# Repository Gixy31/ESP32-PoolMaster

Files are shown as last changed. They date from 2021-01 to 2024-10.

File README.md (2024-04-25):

<h2>ESP32 PoolMaster</h2>
<h4>Brief description</h4>
<p> This project is a software port to an ESP32 platform of the PoolMaster project from Loic74650 (https://github.com/Loic74650/PoolMaster)<br />
Compared to the initial project, the main differences are:
<ul>
  <li> ESP32 MCU with WiFi (multiple access points)</li>
  <li> ESP32-Arduino framework, PlatformIO IDE </li>
  <li> async MQTT client</li>
  <li> JSON upgrade to version 6</li>
  <li> lots of code modifications, keeping the general behaviour</li>
  <li> add a fourth pump (cleaning robot)</li>
  <li> manage only 2 relays (+ the four pumps)</li>
  <li> analog measurements done by external ADC I2C module (ADS1115), in async mode</li>
  <li> and more...
</ul>  <br />
  The project isn't a fork of the original one due to the different structure of source files with PlatformIO ((.cpp, .h).
  A dedicated board has been designed to host all components. There are 8 LEDs at the bottom to display status, warnings and alarms.
  <br /><br />
  In version ESP-3.0, the display function has been very simplified (twice less code), using Nextion variables only to deport the logic 
  into the Nextion and updating the display only when it is ON. 
  <br /><br />
  A new version of the board allows the connection of the pH_Orp board from Loïc (https://github.com/Loic74650/pH_Orp_Board/tree/main)  on an additional I2C connector. The sofware is modified accordingly. The configuration is defined in the config.h file. CAD_files 2 Gerber 3 files are provided.
  <br /><br />
  The version V6, (aka ESP-2.0) implement direct usage of FreeRTOS functions for managing tasks and queues. There are 10 tasks sharing the
  app_CPU :
  - The Arduino loopTask, with only the setup() function. When the setup is finished, the task deletes itself to recover memory;
  - PoolMaster, running every 500ms, which mainly supervises the overall timing of the system;
  - AnalogPoll, running every 125ms, to acquire analog measurements of pH, ORP and Pressure with an ADS115 sensor on an I2C bus;
  - GetTemp, running every 1000ms, to acquire water and air temperatures with DS18B20 sensors on two 1Wire busses;
  - ORPRegulation, running every 1000ms, to manage Chlorine pump;
  - pHRegulation, running every 1000ms, to manage Acid/Soda pump;
  - ProcessCommand, running every 500ms, to process commands received on /Home/Pool6/API MQTT Topic;
  - SettingsPublish, running when notified only (e.g with external command), to publish settings on the MQTT topic;
  - MeasuresPublish, running every 30s and when notified, to publish actual measures and status;
  - StatusLights, running every 3000ms, to display a row of 8 status LEDs on the mother board, through a PCF8574A on the I2C bus.

  </p><br /><br />

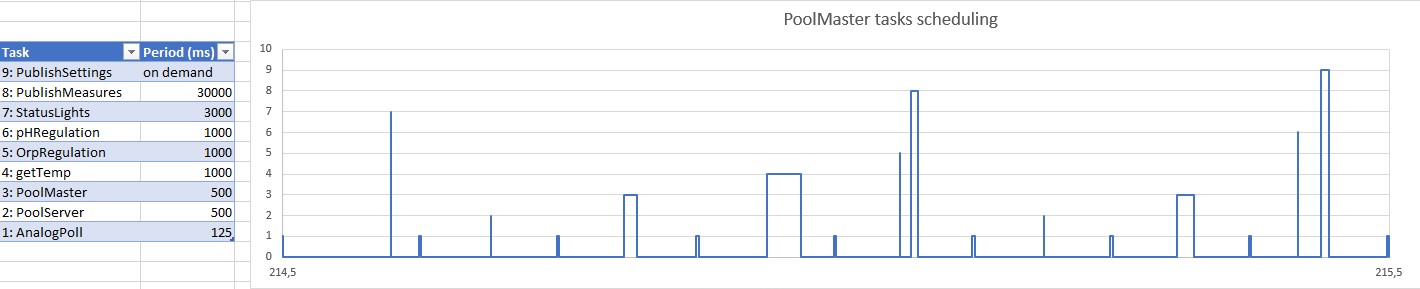
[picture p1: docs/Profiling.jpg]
  <br /><br />
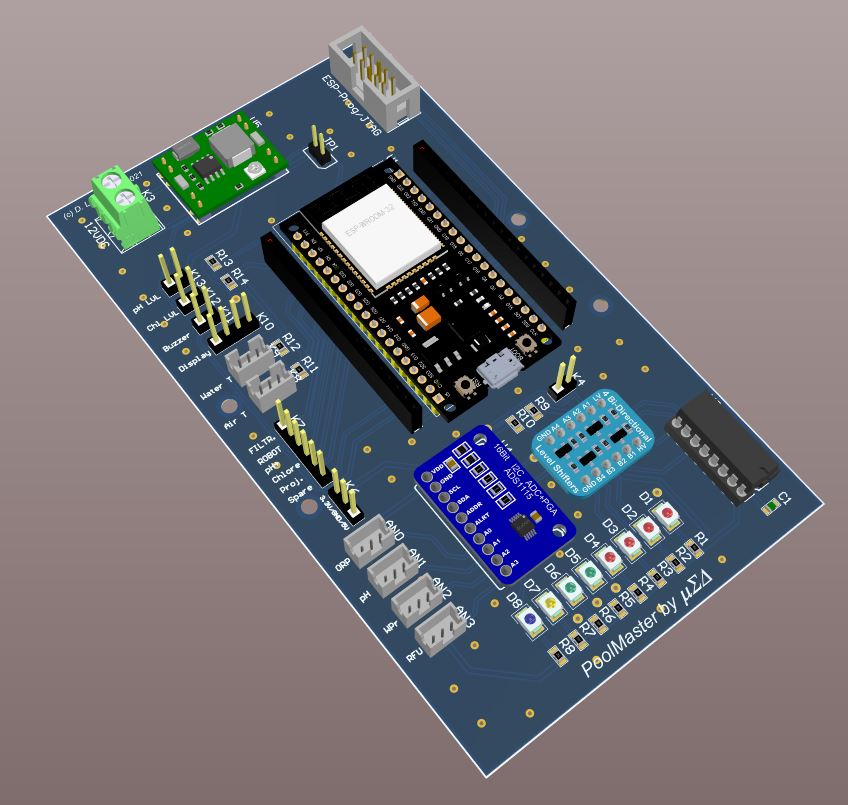
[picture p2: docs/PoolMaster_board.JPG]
Board
 <br /><br />  
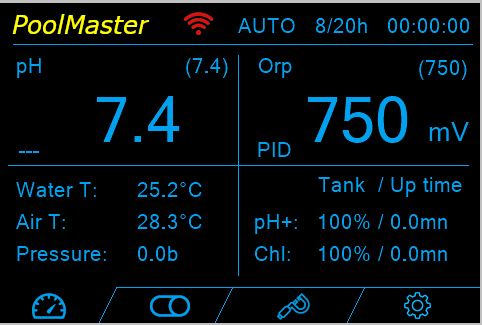
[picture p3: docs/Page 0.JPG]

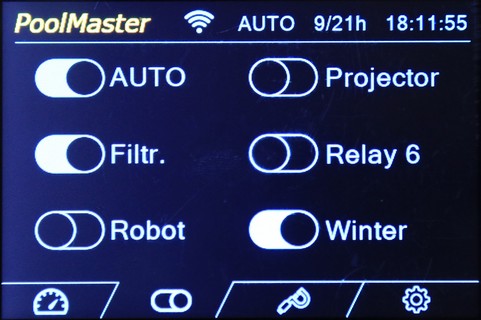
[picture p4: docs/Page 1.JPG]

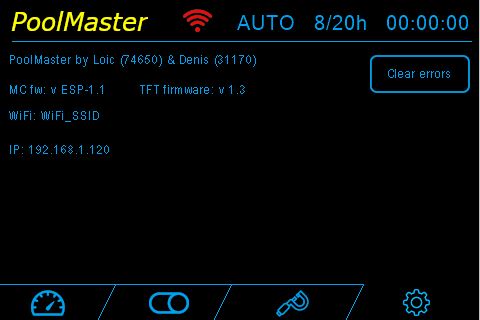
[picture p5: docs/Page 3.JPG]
<br /><br />  

<h2>PoolMaster 5.0.0</h2>
<h2>Arduino Mega2560 (or Controllino-Maxi) Ph/Orp (Chlorine) regulation system for home pools</h2>

<br />
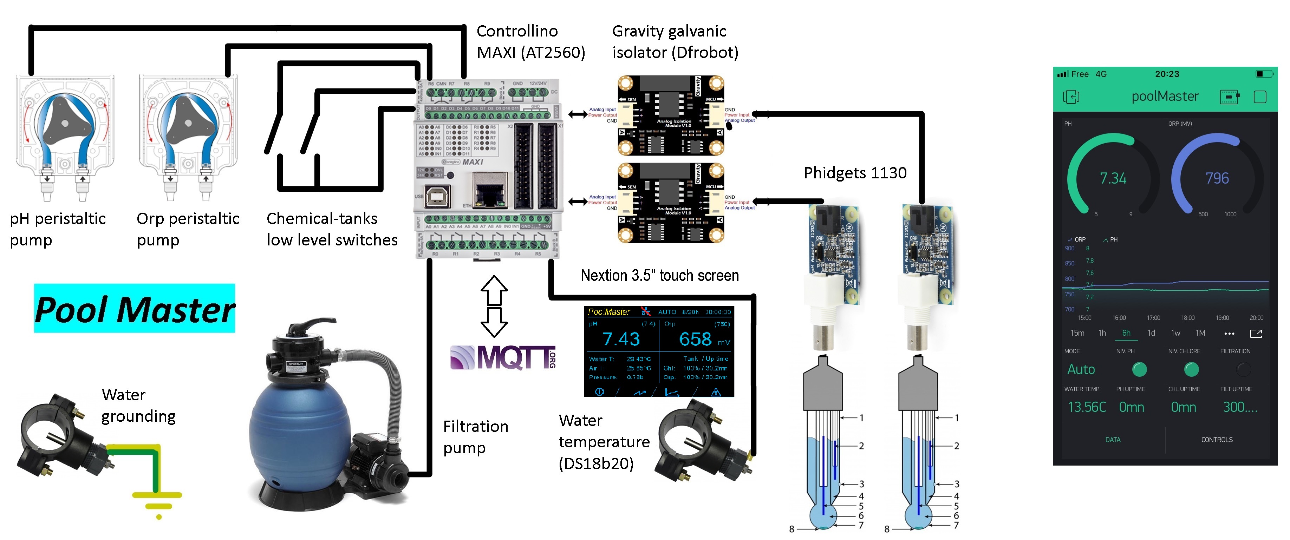
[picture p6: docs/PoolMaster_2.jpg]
 <br /><br />

<br />
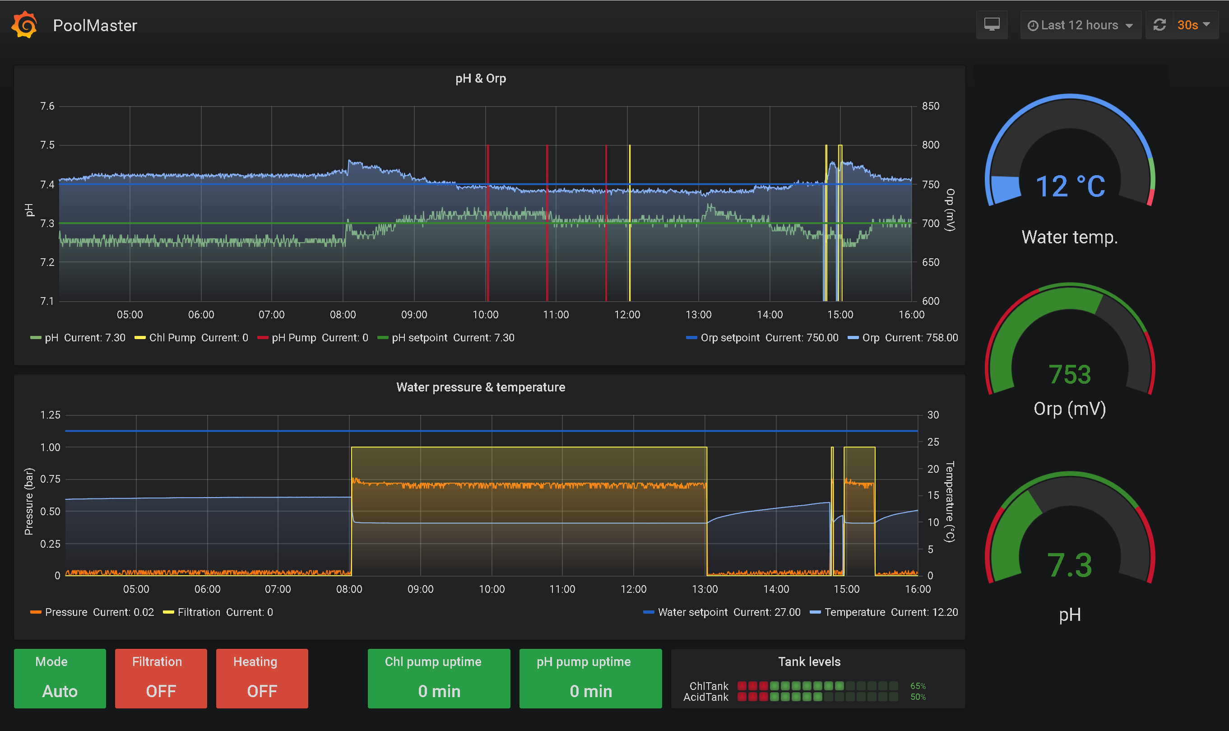
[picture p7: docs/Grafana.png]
Dashboard
 <br /><br />

<br />
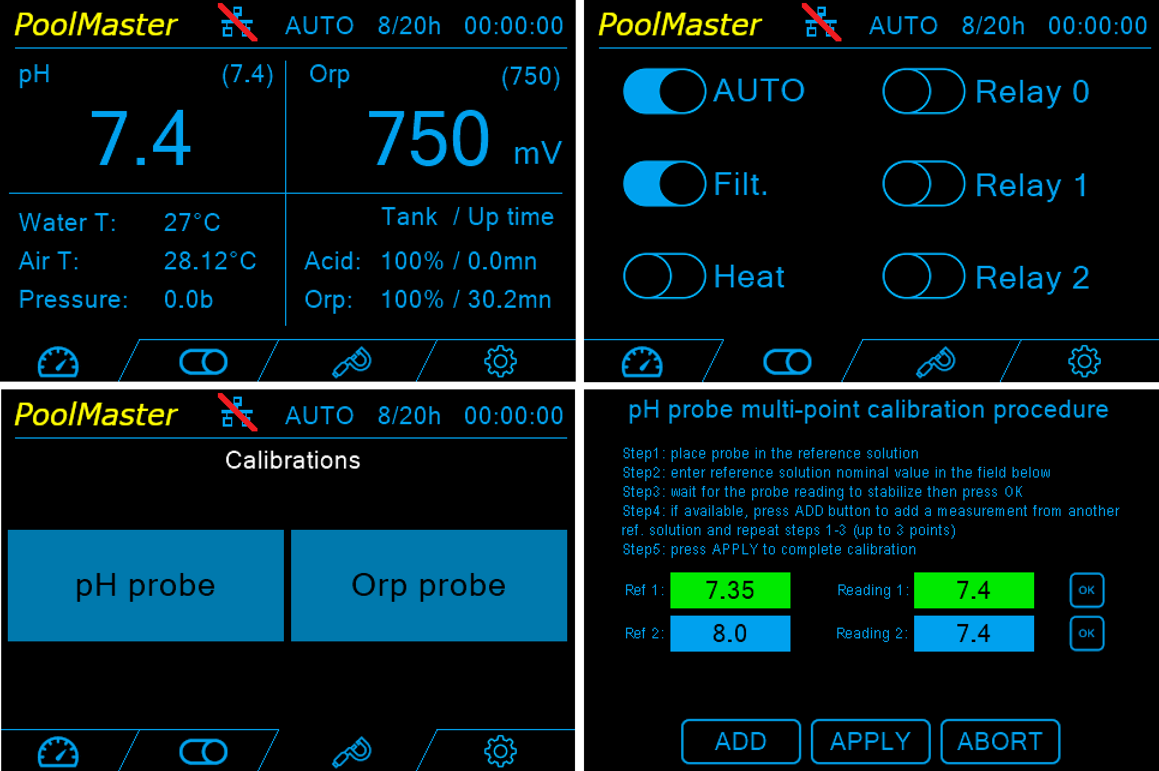
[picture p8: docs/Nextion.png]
Nextion 3.5
<p align="center"> 
Pumps states, tank-levels estimates and other parameters are also periodically reported<br />
Two PID regulation loops are running in parallel: one for PH, one for ORP<br />
An additional simple (on/off) regulation loop is handling the water temperature (it starts/stops the house-heating system circulator which brings heat to a heat exchanger mounted on the pool water pipes)<br />
pH is regulated by injecting Acid from a tank into the pool water (a relay starts/stops the Acid peristaltic pump)<br />
ORP is regulated by injecting Chlorine from a tank into the pool water (a relay starts/stops the Chlorine peristaltic pump)<br />
Defined time-slots and water temperature are used to start/stop the filtration pump for a daily given amount of time (a relay starts/stops the filtration pump)<br />
Tank-levels are estimated based on the running-time and flow-rate of each pump.<br />
Ethernet connectivity parameters can be set through a webpage accessible from the LAN at http://PoolMaster.local.<br />
If an ethernet connection is available, the internal clock (RTC) is synchronized with a time-server every day at midnight.<br />

An API function enables telling the system what the outside air temperature is. In case it is below -2.0°C, filtration is started until it rises back above +2.0°C<br />
Communication with the system is performed using the MQTT protocol over an Ethernet connection to the local network/MQTT broker.<br /><br />

Every 30 seconds (by default), the system will publish on the "PoolTopicMeas1" and "PoolTopicMeas2"(see in code below) the following payloads in Json format:<br />
  {"Tmp":818,"pH":321,"PSI":56,"Orp":583,"FilUpT":8995,"PhUpT":0,"ChlUpT":0}<br />
  {"AcidF":100,"ChlF":100,"IO":11,"IO2":0}<br />
  Tmp: measured Water temperature value in °C x100 (8.18°C in the above example payload)<br />
  pH: measured pH value x100 (3.21 in the above example payload)<br />
  Orp: measured Orp (aka Redox) value in mV (583mV in the above example payload)<br />
  PSI: measured Water pressure value in bar x100 (0.56bar in the above example payload)<br />
  FiltUpT: current running time of Filtration pump in seconds (reset every 24h. 8995secs in the above example payload)<br />
  PhUpT: current running time of Ph pump in seconds (reset every 24h. 0secs in the above example payload)<br />
  ChlUpT: current running time of Chl pump in seconds (reset every 24h. 0secs in the above example payload)<br />
  AcidF: percentage fill estimate of acid tank ("pHTank" command must have been called when a new acid tank was set in place in order to have accurate value)<br />
  ChlF: percentage fill estimate of Chlorine tank ("ChlTank" command must have been called when a new Chlorine tank was set in place in order to have accurate value)<br />
IO: a variable of type BYTE where each individual bit is the state of a digital input on the Arduino. These are :<br />	
<ul>
<li>FiltPump: current state of Filtration Pump (0=on, 1=off)</li>
<li>PhPump: current state of Ph Pump (0=on, 1=off)</li>
<li>ChlPump: current state of Chl Pump (0=on, 1=off)</li>
<li>PhlLevel: current state of Acid tank level (0=empty, 1=ok)</li>
<li>ChlLevel: current state of Chl tank level (0=empty, 1=ok)</li>
<li>PSIError: over-pressure error</li>
<li>pHErr: pH pump overtime error flag</li>
<li>ChlErr: Chl pump overtime error flag</li>
</ul><br />
IO2: a variable of type BYTE where each individual bit is the state of a digital input on the Arduino. These are :<br /><br />
<ul>
<li>pHPID: current state of pH PID regulation loop (1=on, 0=off)</li>
<li>OrpPID: current state of Orp PID regulation loop (1=on, 0=off)</li>
<li>Mode: state of pH and Orp regulation mode (0=manual, 1=auto)</li>
<li>Heat: state of water heat command (0=off, 1=on)</li>
<li>R1: state of Relay1 (0=off, 1=on)</li>
<li>R2: state of Relay2 (0=off, 1=on)</li>
<li>R6: state of Relay6 (0=off, 1=on)</li>
<li>R7: state of Relay7 (0=off, 1=on)</li>
</ul><br />

<h4>How to compile</h4>
<p>
- this code was developped for two main hardware configurations (see list in the hardware section below):<br /> 
<ul>
<li>Controllino-Maxi or</li> 
<li>Arduino Mega 2560 + Ethernet shield + relay shield + RTC module</li></ul>
- select the target board type in the Arduino IDE (either "Arduino Mega 2560" or "Controllino Maxi") code should compile for both types<br />

<h4>Compatibility</h4>
	
<p>For this sketch to work on your setup you must change the following in the code (in the "Config.h" file):<br />
- possibly the pinout definitions depending on your wiring<br />
- the unique address of the DS18b20 water temperature sensor<br />
- MAC and IP address of the Ethernet shield<br />
- MQTT broker IP address and login credentials<br />
- possibly the topic names on the MQTT broker to subscribe and publish to<br />
- the Kp,Ki,Kd parameters for both PID loops in case your peristaltic pumps have a different throughput than 1.5Liters/hour for the pH pump and 3.0Liters/hour for the Chlorine pump. Also the default Kp values were adjusted for a 50m3 pool volume. You might have to adjust the Kp values in case of a different pool volume and/or peristaltic pumps throughput (start by adjusting it proportionally). In any case these parameters are likely to require adjustments for every pool<br /></p>

<h4>Tips</h4>
Before attempting to regulate your pool water with this automated system, it is essential that you start with:<br />
1- testing your water quality (using liquid kits and/or test strips for instance) and balancing it properly (pH, Chlorine, Alkalinity, Hardness). Proper water balancing will greatly ease the pH stability and regulation<br />
2- calibrating the pH probe using calibrated buffer solutions (pay attention to the water temperature which plays a big role in pH readings)<br />
3- adjusting pH to 7.4 <br />
4- once above steps 1 to 3 are ok, you can start regulating ORP<br /><br />
 
Notes:<br />
a/ the ORP sensor should theoretically not be calibrated nore temperature compensated (by nature its 0mV pivot point cannot shift)<br />
b/ the ORP reading is strongly affected by the pH value and the water temperature. Make sure pH is adjusted at 7.4<br />
c/ prefer platinium ORP probes for setpoints >500mV (ie. Pools and spas)<br />
e/ the response time of ORP sensors can be fast in reference buffer solutions (10 secs) and yet very slow in pool water (minutes or more) as it depends on the water composition <br /><br />

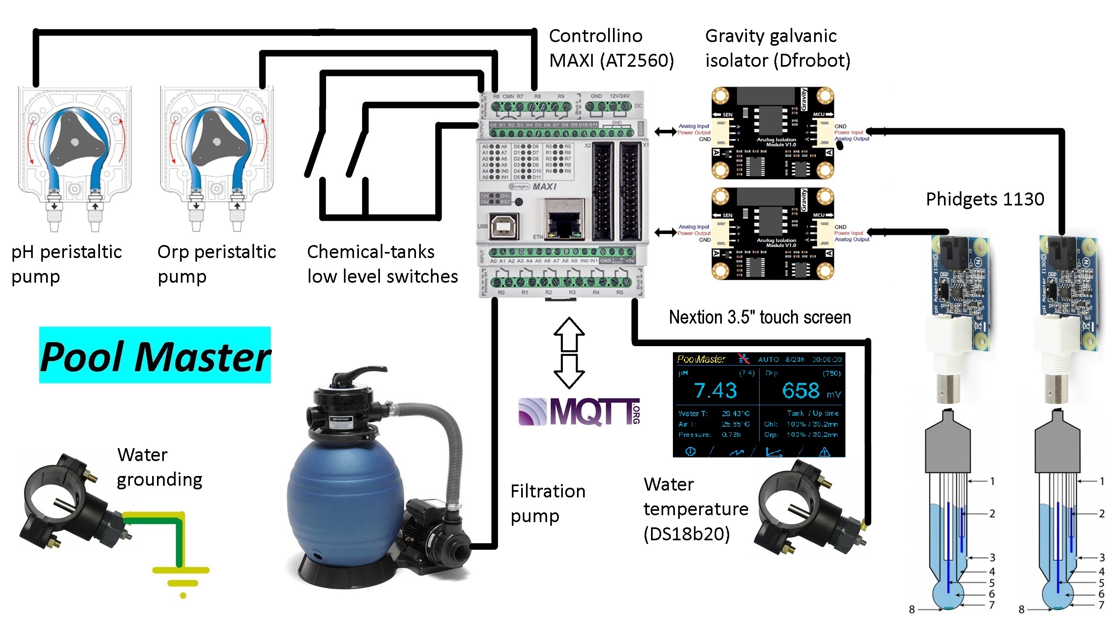
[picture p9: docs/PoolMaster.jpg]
 <br /><br />
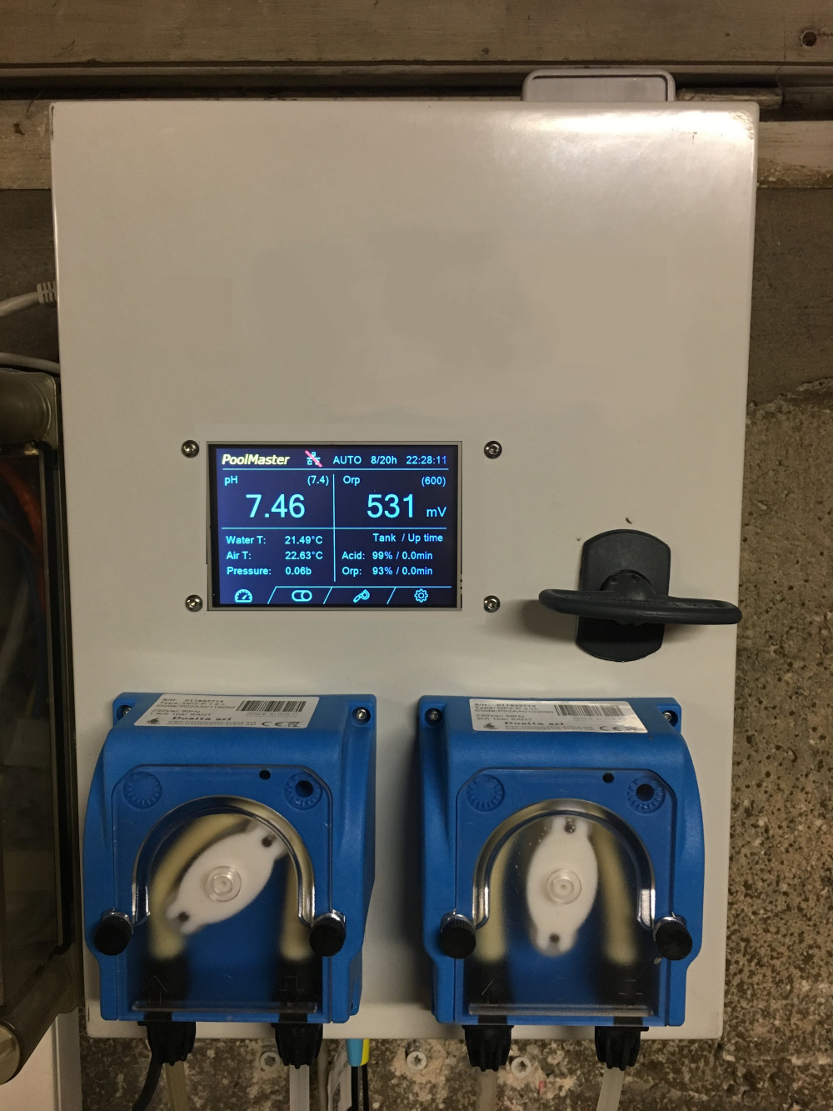
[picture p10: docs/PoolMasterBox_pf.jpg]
 <br /><br />

<h4>MQTT API</h4>
<p>
Below are the Payloads/commands to publish on the "PoolTopicAPI" topic (see hardcoded in code) in Json format in order to launch actions on the Arduino:<br />
<ul>
<li>{"Mode":1} or {"Mode":0}         -> set "Mode" to manual (0) or Auto (1). In Auto, filtration starts/stops at set times of the day and pH and Orp are regulated</li> 
<li>{"Heat":1} or {"Heat":0}         -> start/stop the regulation of the pool water temperature</li>
<li>{"FiltPump":1} or {"FiltPump":0} -> manually start/stop the filtration pump</li>
<li>{"ChlPump":1} or {"ChlPump":0}   -> manually start/stop the Chl pump to add more Chlorine</li>
<li>{"PhPump":1} or {"PhPump":0}     -> manually start/stop the Acid pump to lower the Ph</li>
<li>{"PhPID":1} or {"PhPID":0}       -> start/stop the Ph PID regulation loop</li>
<li>{"OrpPID":1} or {"OrpPID":0}     -> start/stop the Orp PID regulation loop</li>
<li>{"PhCalib":[4.02,3.8,9.0,9.11]}  -> multi-point linear regression calibration (minimum 1 point-couple, 6 max.) in the form [ProbeReading_0, BufferRating_0, xx, xx, ProbeReading_n, BufferRating_n]
<li>{"OrpCalib":[450,465,750,784]}   -> multi-point linear regression calibration (minimum 1 point-couple, 6 max.) in the form [ProbeReading_0, BufferRating_0, xx, xx, ProbeReading_n, BufferRating_n]
<li>{"PhSetPoint":7.4}               -> set the Ph setpoint, 7.4 in this example</li>
<li>{"OrpSetPoint":750.0}            -> set the Orp setpoint, 750mV in this example</li>
<li>{"WSetPoint":27.0}               -> set the water temperature setpoint, 27.0deg in this example</li>
<li>{"WTempLow":10.0}                -> set the water low-temperature threshold below which there is no need to regulate Orp and Ph (ie. in winter)</li>
<li>{"OrpPIDParams":[2857,0,0]}      -> respectively set Kp,Ki,Kd parameters of the Orp PID loop. In this example they are set to 2857, 0 and 0</li>
<li>{"PhPIDParams":[1330000,0,0.0]}  -> respectively set Kp,Ki,Kd parameters of the Ph PID loop. In this example they are set to 1330000, 0 and 0</li>
<li>{"OrpPIDWSize":3600000}           -> set the window size of the Orp PID loop in msec, 60mins in this example</li>
<li>{"PhPIDWSize":1200000}            -> set the window size of the Ph PID loop in msec, 20mins in this example</li>
<li>{"Date":[1,1,1,18,13,32,0]}      -> set date/time of RTC module in the following format: (Day of the month, Day of the week, Month, Year, Hour, Minute, Seconds), in this example: Monday 1st January 2018 - 13h32mn00secs</li>
<li>{"FiltT0":9}                     -> set the earliest hour (9:00 in this example) to run filtration pump. Filtration pump will not run beofre that hour</li>
<li>{"FiltT1":20}                    -> set the latest hour (20:00 in this example) to run filtration pump. Filtration pump will not run after that hour</li>
<li>{"PubPeriod":30}                 -> set the periodicity (in seconds) at which the system info (pumps states, tank levels states, measured values, etc) will be published to the MQTT broker</li>
<li>{"PumpsMaxUp":1800}              -> set the Max Uptime (in secs) for the Ph and Chl pumps over a 24h period. If over, PID regulation is stopped and a warning flag is raised</li>
<li>{"Clear":1}                      -> reset the pH and Orp pumps overtime error flags in order to let the regulation loops continue. "Mode" also needs to be switched back to Auto (1) after an error flag was raised</li>
<li>{"DelayPID":30}                  -> Delay (in mins) after FiltT0 before the PID regulation loops will start. This is to let the Orp and pH readings stabilize first. 30mins in this example. Should not be > 59mins</li>
<li>{"TempExt":4.2}                  -> Provide the system with the external temperature. Should be updated regularly and will be used to start filtration when temperature is less than 2°C. 4.2deg in this example</li>
<li>{"PSIHigh":1.0}                  -> set the water high-pressure threshold (1.0bar in this example). When water pressure is over that threshold, an error flag is set</li>
<li>{"pHTank":[20,100]}              -> call this function when the Acid tank is replaced or refilled. First parameter is the tank volume in Liters, second parameter is its percentage fill (100% when full)</li>
<li>{"ChlTank":[20,100]}             -> call this function when the Chlorine tank is replaced or refilled. First parameter is the tank volume in Liters, second parameter is its percentage fill (100% when full)</li>
<li>{"Relay":[1,1]}                  -> call this generic command to actuate spare relays. Parameter 1 is the relay number (R1 in this example), parameter 2 is the relay state (ON in this example). This command is useful to use spare relays for additional features (lighting, etc). Available relay numbers are 1,2,6,7,8,9</li>
<li>{"Reboot":1}                     -> call this command to reboot the controller (after 8 seconds from calling this command)</li>
<li>{"pHPumpFR":1.5}                 -> call this command to set pH pump flow rate un L/s. In this example 1.5L/s</li>
<li>{"ChlPumpFR":3}                  -> call this command to set Chl pump flow rate un L/s. In this example 3L/s</li>
<li>{"RstpHCal":1}                   -> call this command to reset the calibration coefficients of the pH probe</li>
<li>{"RstOrpCal":1}                  -> call this command to reset the calibration coefficients of the Orp probe</li>
<li>{"RstPSICal":1}                  -> call this command to reset the calibration coefficients of the pressure sensor</li>

</ul>
</p><br />

<h4>Hardware</h4>
<p>
<ul>
<li><a title="https://www.controllino.biz/product/controllino-maxi/" href="https://www.controllino.biz/product/controllino-maxi/">x1 CONTROLLINO MAXI (ATmega2560)</a> or Arduino Mega 2560 + Ethernet shield + relay shield + RTC module</li>
<li><a title="https://www.phidgets.com/?tier=3&catid=11&pcid=9&prodid=103" href="https://www.phidgets.com/?tier=3&catid=11&pcid=9&prodid=103">x2 Phidgets PH/ORB amplifier modules</a></li> 
<li><a title="https://www.dfrobot.com/product-1621.html" href="https://www.dfrobot.com/product-1621.html">x2 Galvanic isolator for the pH and Orp probes</a></li> 
<li><a title="https://www.trattamento-acque.net/dosaggio/pompe-peristaltiche/pompe-a-portata-fissa/pompa-serie-mp2-p-detail.html" href="https://www.trattamento-acque.net/dosaggio/pompe-peristaltiche/pompe-a-portata-fissa/pompa-serie-mp2-p-detail.html">x2 Peristaltic pumps, suction lances for tanks, pH and Orp probes</a></li>
<li><a title="http://electrolyseur.fr/pool-terre.html" href="http://electrolyseur.fr/pool-terre.html">x1 Water grounding</a></li>
<li><a title="http://electrolyseur.fr/kit-sonde-DS18B20-filtration-piscine.html" href="http://electrolyseur.fr/kit-sonde-DS18B20-filtration-piscine.html">x1 Water temperature probe (DS18B20)</a></li>
<li><a title="https://fr.aliexpress.com/item/OOTDTY-G1-4-Pouces-5-v-0-0-5-MPa-Pression-Capteur-Capteur-D-huile-Carburant/32851667666.html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
" href="https://fr.aliexpress.com/item/OOTDTY-G1-4-Pouces-5-v-0-0-5-MPa-Pression-Capteur-Capteur-D-huile-Carburant/32851667666.html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
">x1 Pressure sensor</a></li>
<li><a title="https://www.itead.cc/nextion-nx4832k035.html" href="https://www.itead.cc/nextion-nx4832k035.html">x1 Nextion Enhanced NX4832K035 - Generic 3.5'' HMI Touch Display</a></li>

</ul>
</p><br />

<h4>Wiring</h4>
<p>
Below is a (quick and dirty) wiring diagram with the Controllino MAXI. Right click and display image in full screen to see the details.
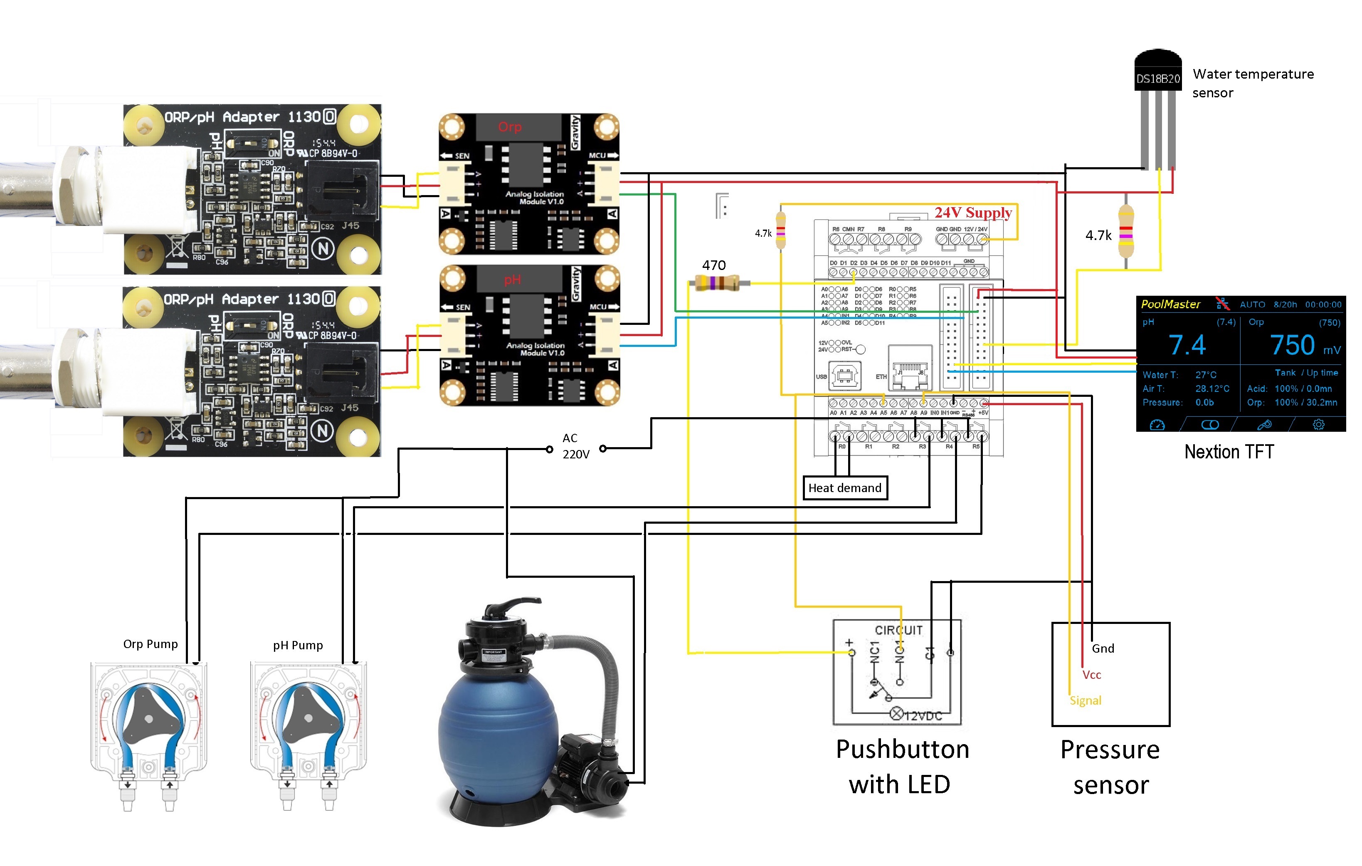
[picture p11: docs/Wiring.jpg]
Wiring
 <br />
</p>

<h4>Cloud integration example (<a title="https://blynk.io/" href="https://blynk.io/">BLYNK</a>)</h4>
<p>
See NodeRed folder for more info and code
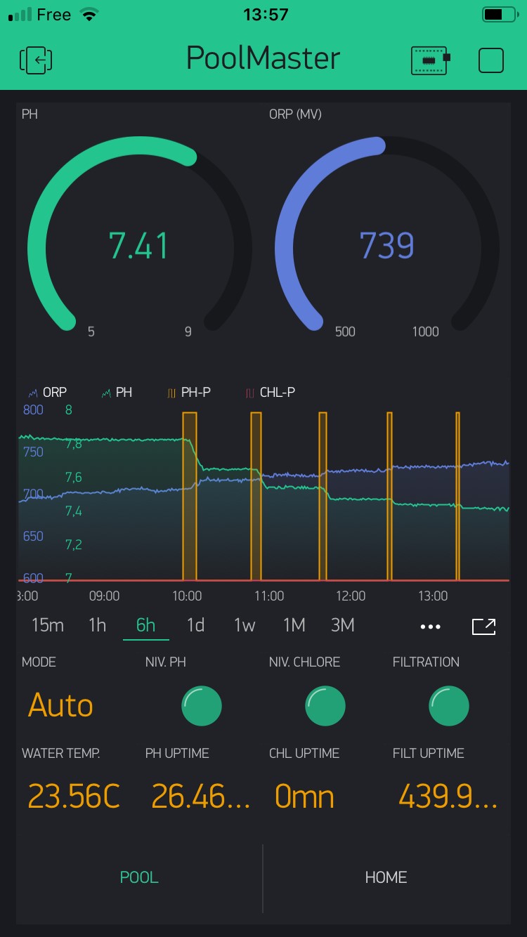
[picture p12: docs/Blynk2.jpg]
Blynk
 <br />
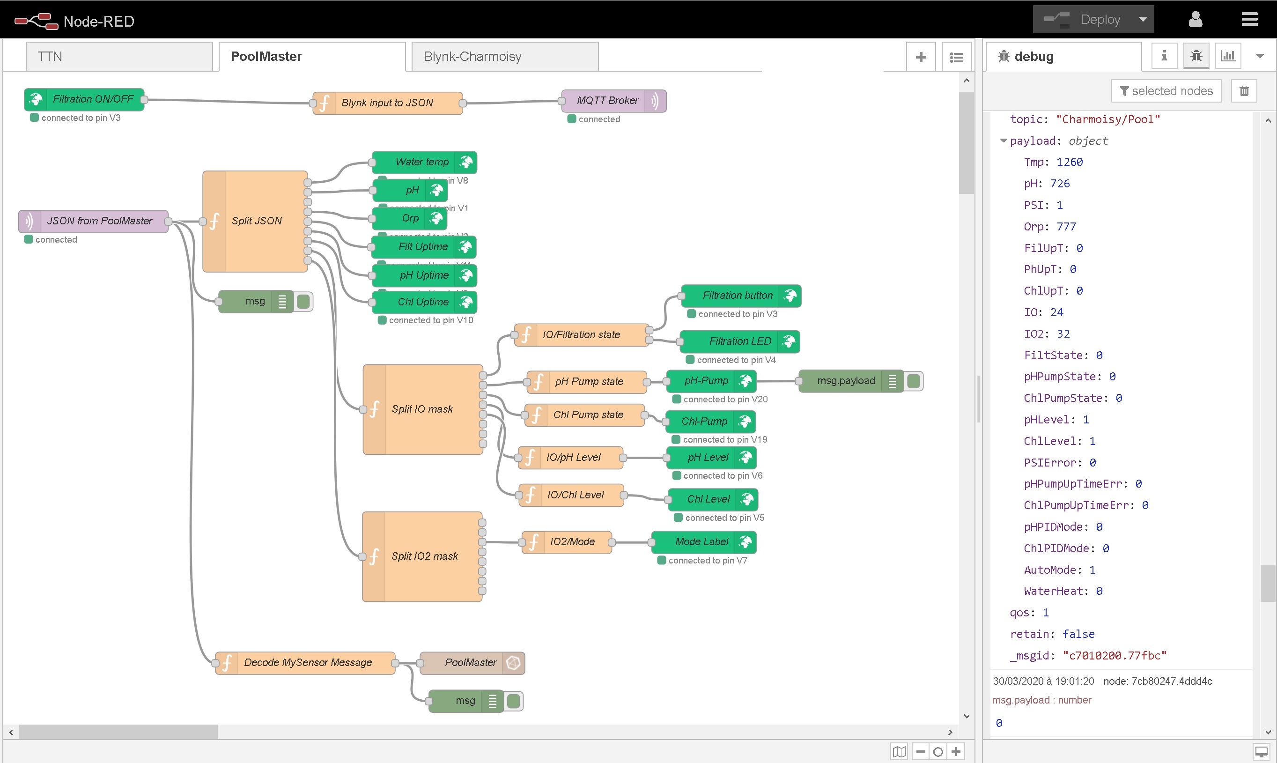
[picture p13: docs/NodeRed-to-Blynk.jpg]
Blynk
 <br />
</p>

<h4>Non-cloud home automation integration example (Node-Red + InfluxDB + Grafana)</h4>
<p>
See the NodeRed folder for more info and this <a title="https://www.youtube.com/watch?v=JdV4x925au0" href="https://www.youtube.com/watch?v=JdV4x925au0">tutorial</a> on how to create a Grafana dashboard from MQTT data.<br />
<p align="center"> Overview </p> <br />
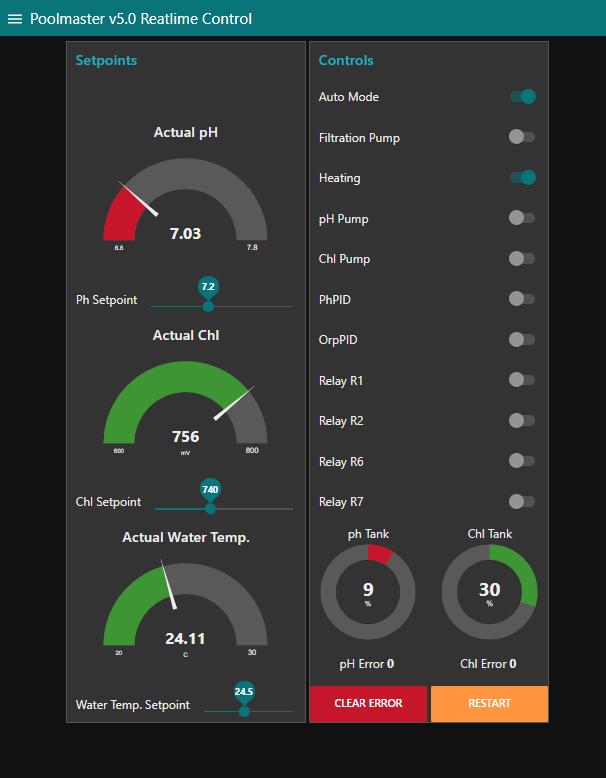
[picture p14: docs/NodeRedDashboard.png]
 <br />

</p>

<h4>Non-cloud home automation integration example (<a title="https://www.jeedom.com" href="https://www.jeedom.com">JEEDOM</a>)</h4>
<p>
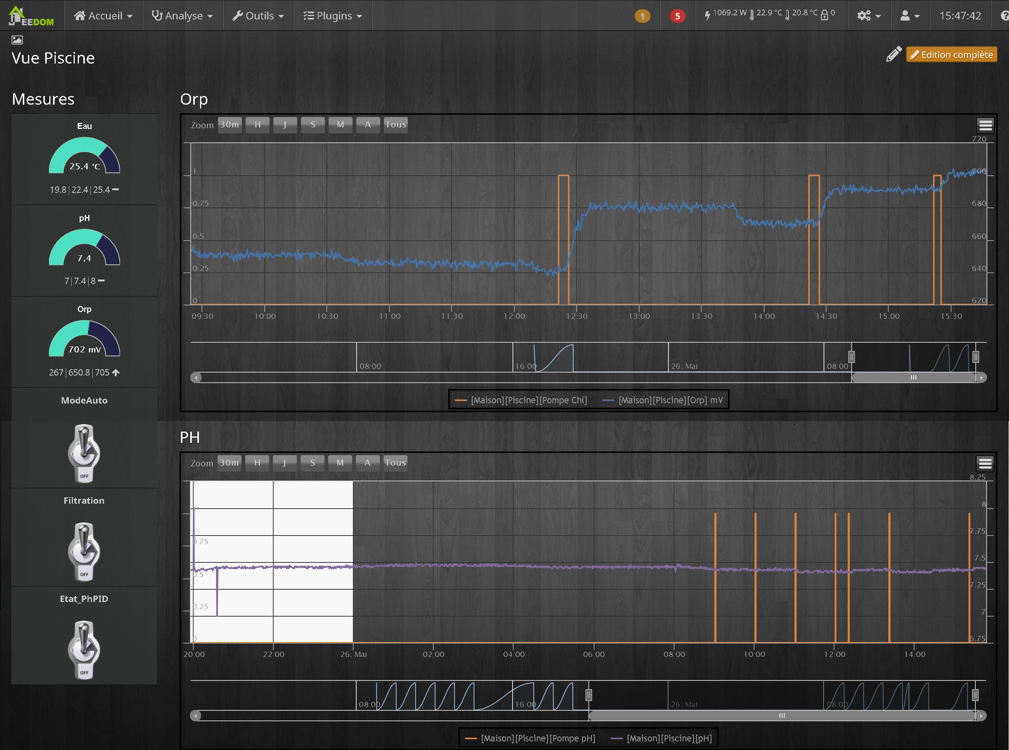
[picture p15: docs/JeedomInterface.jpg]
 <br />
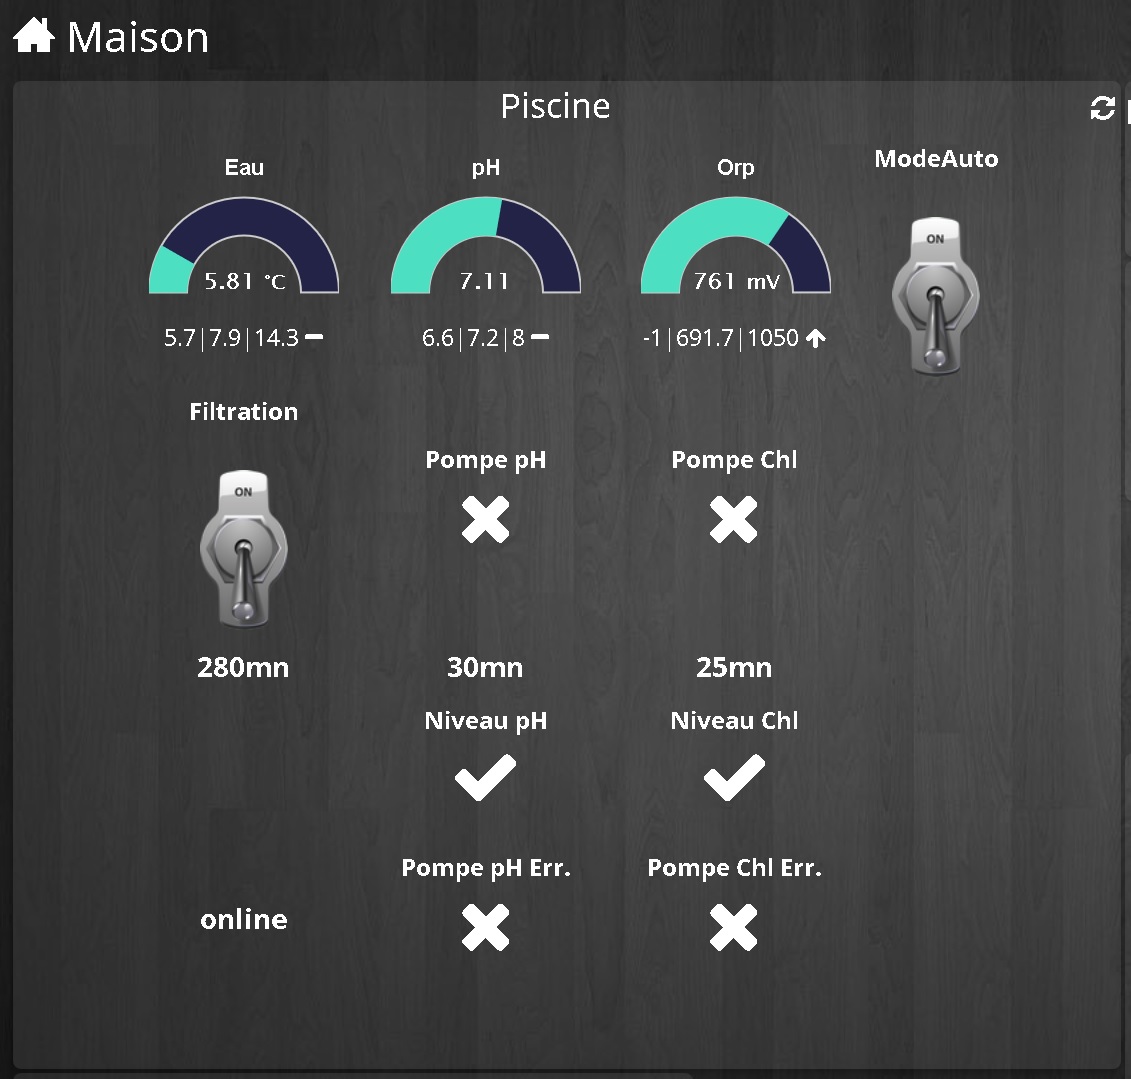
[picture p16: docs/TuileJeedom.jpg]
 <br />
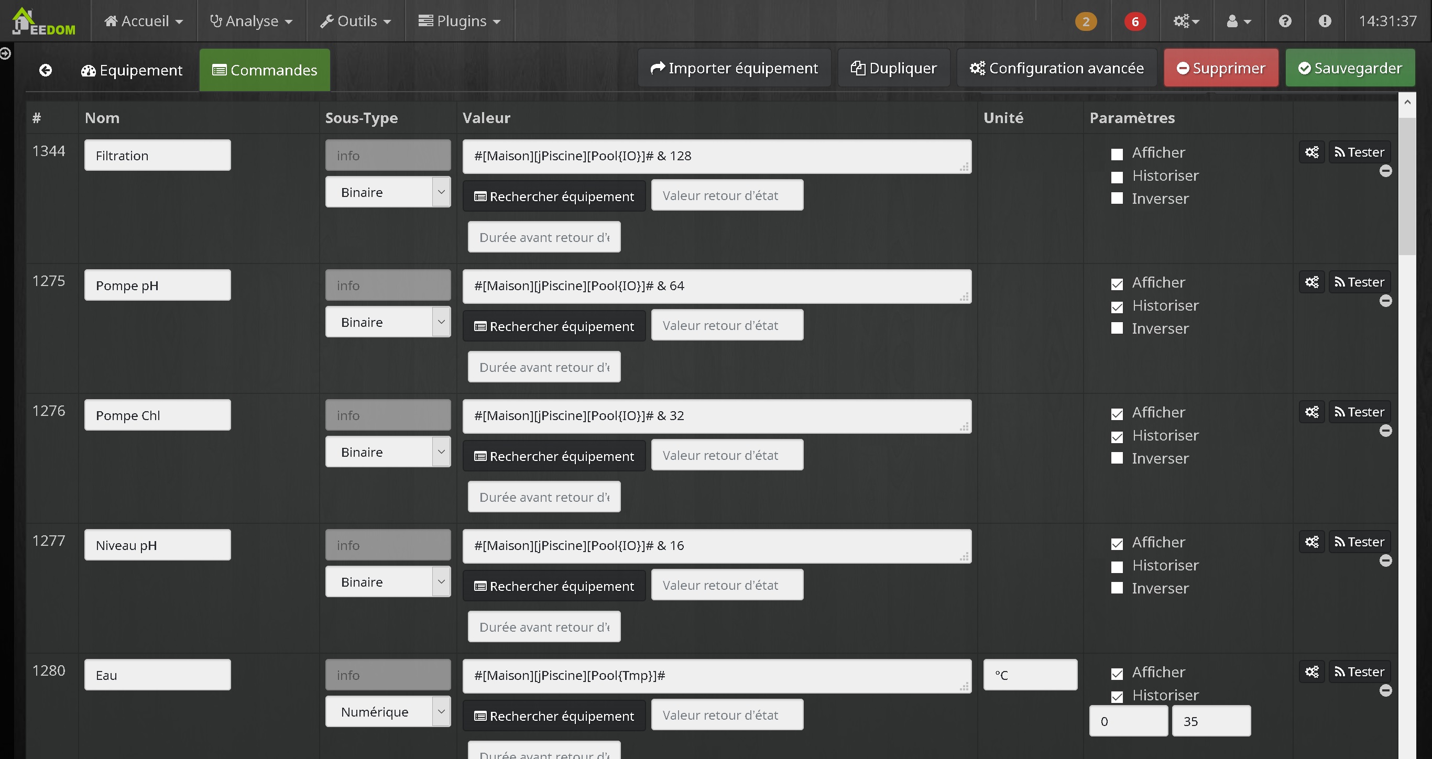
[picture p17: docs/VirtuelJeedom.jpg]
 <br />
</p>

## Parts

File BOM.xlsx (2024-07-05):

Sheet: Feuil1
Objet | lien | Prix Unitaire | Quantité | Prix Total
1 Alimentation MeanWell 12V HDR-30 | https://fr.aliexpress.com/item/4000512714343.html?spm=a2g0s.9042311.0.0.27426c372DwVi7 | 16 | 1 | 16
1 carte fille mega 2560 DIY + connecteur |  | 5 | 1 | 5
cables dupont 30cm | https://fr.aliexpress.com/item/32987024879.html?spm=a2g0s.9042311.0.0.6d836c373sh99I | 3 | 2 | 6
cable PH2.0 dupont | https://fr.aliexpress.com/item/4000983636722.html?spm=a2g0s.9042311.0.0.6d836c373sh99I | 5 | 1 | 5
mega2560 R3 Advanced Keyestudio | https://fr.aliexpress.com/item/32902050141.html?spm=a2g0s.9042311.0.0.27426c37zPn488 | 13 | 1 | 13
W5100 Ethernet Shield Keyestudio | https://fr.aliexpress.com/item/2042247327.html?spm=a2g0s.9042311.0.0.27426c37zPn488 | 8 | 1 | 8
Nextion bordure 6 | https://fr.aliexpress.com/item/4000127982680.html?spm=a2g0s.9042311.0.0.27426c37zPn488 | 6 | 1 | 6
Nextion NX4832K035 | https://fr.aliexpress.com/item/4000127982680.html?spm=a2g0s.9042311.0.0.27426c37zPn488 | 33.59 | 1 | 33.59
DS3231 Clock | https://fr.aliexpress.com/item/33000531103.html?spm=a2g0s.9042311.0.0.27426c37PumqU7 | 3 | 1 | 3
Support Rail DIN plastique | https://fr.aliexpress.com/item/4000539460290.html?spm=a2g0s.9042311.0.0.27426c37PumqU7 | 1.37 | 1 | 1.37
Relay shield | https://fr.aliexpress.com/item/33050594625.html?spm=a2g0s.9042311.0.0.27426c37PumqU7 | 5.7 | 1 | 5.7
Rail din 20cm | https://fr.aliexpress.com/item/32903957266.html?spm=a2g0s.9042311.0.0.27426c3755H1y5 | 2 | 2 | 4
sonde pression | https://fr.aliexpress.com/item/32851667666.html?spm=a2g0s.9042311.0.0.27426c3755H1y5 | 11 | 1 | 11
Connecteur RJ45 | https://fr.aliexpress.com/item/32901871650.html?spm=a2g0s.9042311.0.0.27426c37qMQp8c | 7 | 1 | 6
boitier legrand Marina | ebay | 60 | 1 | 60
tole galvanisé 300x200 | ebay | 11 | 1 | 11
pompe peristatique PR4 SEKO | ebay | 130 | 2 | 260
sonde PH Hanna |  | 70 | 1 | 70
Sonde ORP |  | 70 | 1 | 70
sonde temperature DS18B20 | https://fr.aliexpress.com/item/32983291667.html | 7.54 | 1 | 7.54
Module d'isolation de signal DFR0504 | https://www.gotronic.fr/art-module-d-isolation-de-signal-dfr0504-27832.htm | 21.9 | 2 | 44
Adaptateur pH/ORP 1130 | https://www.gotronic.fr/art-adaptateur-ph-orp-1130-12112.htm | 30.5 | 2 | 71
2 Relay de puissance 2P 25A 2NO 220V | https://fr.aliexpress.com/item/4000198627842.html?spm=a2g0s.9042311.0.0.27426c37qVlc3P | 6.68 | 2 | 13
(commande Lumiere + electrovanne )
Disjoncteur C2 |  | 15 | 1 | 15
1 kit mise à la terre poolterre |  | 50 | 1 | 50
accessoires divers |  | 20 | 1 | 20
 |  |  | total | 815.2

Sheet: Feuil2
water pressure sensor (0-5 bar) G3/8 | https://fr.aliexpress.com/item/1005004270144334.html | 8.50 €
Power supply 12V-2A 30W Meanwell HDR-30-12 | https://fr.aliexpress.com/item/1005006593795657.html | 17.55 €
5x2 PCB DIN supports DRG-01 PCB | https://fr.aliexpress.com/item/1005006226938330.html | 3.48 €
Active Buzzer | https://fr.aliexpress.com/item/32849730395.html | 1.46 €
Bidirectionnal Level Shifter | https://fr.aliexpress.com/item/1005006165104615.html | 2.28 € | note: use small diameter header pins (PCB has small holes)
6x5V relays module | https://fr.aliexpress.com/item/32649659086.html | 3.78 €
ADC 4 chanels 16bits ADS1115 | https://fr.aliexpress.com/item/1005006864351047.html | 1.80 €
ESP32-DevKitC-32E (V4) Type-C ESP-32 38PIN | https://fr.aliexpress.com/item/1005006345005109.html | 4.05 €
LEDs 1206 5x100pc | https://fr.aliexpress.com/item/1005006314040384.html | 1.82 €
Air temperature probe - DS18B20 3m | https://fr.aliexpress.com/item/1005006431677780.html | 2.50 €
Converter DC-DC MP1584 x5 | https://fr.aliexpress.com/item/1005005870392716.html | 2.77 € | note: use small diameter header pins (PCB has small holes)
Nextion display frame | https://fr.aliexpress.com/item/1005005316482964.html | 3.62 €
Display Nextion Enhanced NX4832K035 | https://fr.aliexpress.com/item/32825642261.html | 38.90 €
Carte PH ORP Gix |  | 35.60 €
Carte poolmaster ESP 32 |  | 5.00 €
Connecteur HE10 10pin droit | https://fr.aliexpress.com/item/1005005364262476.html | 1.33 €
Borniers à vis 2EDG 5.08mm Right Angle | https://fr.aliexpress.com/item/1005002464961832.html | 1.67 €
PCF8574AN | https://fr.aliexpress.com/item/1005006711674905.html | 3.96 €
CAPA 100nf 0805 | https://fr.aliexpress.com/item/1005005690917856.html | 1.16 €
JST-1x3 M (2 mm pitch) connectors PH2,0 | https://fr.aliexpress.com/item/33001807525.html | 2.39 €
All resistors and capacitors | Size 0805 | 5.00 €
T 1/4" pipe connector | https://fr.aliexpress.com/item/4000195262654.html | 3.78 €
DIN rail alu 2x25cm | https://fr.aliexpress.com/item/1005001553239891.html? | 3.94 €
Microdos pH probe | https://www.my-pool-covers.com/shop/sonde-ph-dosage-automatique-12435?category=328#attr=14030 | 60.00 €
Microdos Redox probe | https://www.my-pool-covers.com/shop/sonde-redox-dosage-automatique-12436?category=328#attr=14032 | 66.55 €
Analyze room (double) | https://www.bypiscine.com/traitement-piscine/accessoires-pompes-doseuses-regulateurs/double-chambre-analyse-piscine-pour-sondes-ph-redox | 109.00 €
Chlorine calibration solution 650mV | https://www.my-pool-covers.com/shop/mpc-00-042-965-solution-etalon-pour-calibration-chlore-650-mv-12459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 | 10.00 €
Chlorine calibration solution 468mV | https://www.my-pool-covers.com/shop/mpc-00-042-904-solution-etalon-pour-calibration-chlore-468-mv-12460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 | 10.00 €
pH calibration solution pH 7 | https://www.my-pool-covers.com/shop/mpc-00-042-902-solution-etalon-pour-calibration-ph-7-12462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 | 7.50 €
pH calibration solution pH 4 | https://www.my-pool-covers.com/shop/mpc-00-042-901-solution-etalon-pour-calibration-ph-4-12463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 | 7.50 €
Support collar 50mm 1/2" x2 | https://www.my-pool-covers.com/shop/mpc-1003008-collier-de-prise-en-charge-50mm-avec-entree-filetee-1-2-12467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 | 19.00 €
Pool grounding 50mm | https://www.my-pool-covers.com/shop/mpc-00-063-805-pool-terre-pour-tuyaux-en-50mm-12469?category=328 | 34.50 €
Microdos peristaltic pump 1,5l/h x2 | https://www.my-pool-covers.com/shop/mpc-mp2-r1-5l-h-mp2-pompe-doseuse-peristaltique-15l-h-12440 | 180.00 €
ABS case 350x250x150mm | https://www.amazon.fr/gp/product/B07C7X9K5R/ref=ppx_yo_dt_b_asin_title_o00_s00?ie=UTF8&psc=1 | 41.45 €
 |  | 701.84 €

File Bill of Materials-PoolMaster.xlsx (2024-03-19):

Comment | Description | Designator | Footprint | LibRef | Quantity
HEADER 3 |  | AN0, AN1, AN2, AN3 | JST-1X3 | HEADER 3 | 4
100n | Capacitor | C1 | 0805C-GENERIC | CAP | 1
Red |  | D1, D2, D3, D4 | TOPLED-RED | LED | 4
Green |  | D5, D6 | TOPLED-GREEN | LED | 2
Yellow |  | D7 | TOPLED-YELLOW | LED | 1
Blue |  | D8 | TOPLED-BLUE | LED | 1
U/L | Jumper | JP1 | 2_PADS | JUMPER | 1
Header 19 | Header, 19-Pin | K1, K2 | HDR1X19 | Header 19 | 2
12VDC | Header, 2-Pin | K3 | MKDS15_2RMI | Header 2 | 1
I2C | Header, 2-Pin | K4 | HEADER-1X2 | Header 2 | 1
ESP-Prog/JTAG | Header, 5-Pin, Dual row | K5 | HE10_10 | Header 5X2 | 1
HEADER 3 |  | K6 | HEADER-1X3 | HEADER 3 | 1
HEADER 6 |  | K7 | HEADER-1X6 | HEADER 6 | 1
Air T | Header, 3-Pin | K8 | JST-1X3 | Header 3 | 1
Water T | Header, 3-Pin | K9 | JST-1X3 | Header 3 | 1
Display | Header, 4-Pin | K10 | HEADER-1X4 | Header 4 | 1
Buzzer | Header, 3-Pin | K11 | HEADER-1X3 | Header 3 | 1
Chl LVL | Header, 2-Pin | K12 | HEADER-1X2 | Header 2 | 1
pH LVL | Header, 2-Pin | K13 | HEADER-1X2 | Header 2 | 1
I2C-5V | Header, 4-Pin | K14 | HEADER-1X4 | Header 4 | 1
3k3 | Resistor | R1, R2, R3, R4, R5, R6, R7, R8 | 0805R-3K3 | RES2 | 8
10k | Resistor | R11, R12, R13, R14 | 0805R-10K | RES2 | 4
ESP32-DEVKITC-32E | - Transceiver; 802.11 b/g/n _Wi-Fi, WiFi, WLAN_, BluetoothÂ® Smart Ready 4.x Dual Mode For Use With ESP-WROOM-32 | U1 | MODULE_ESP32-DEVKITC-32D | ESP32-DEVKITC-32D | 1
PCF8574AN | Remote 8-Bit I/O Expander for I2C-Bus, 2.5 to 6 V, -40 to 85 degC, 16-pin PDIP (N), Pb-Free (RoHS) | U2 | DIP16 | PCF8574AN | 1
SHIFTER 4CH |  | U3 | SHIFTER 4CH | SHIFTER 4CH | 1
ADS1115 |  | U4 | ADS1115 Module | ADS1115 | 1
MP1584EN |  | U5 | MP1884EN | MP1584EN | 1

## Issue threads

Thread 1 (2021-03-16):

I can't compile code  error: aggregate 'tm timeinfo'

drivers1, 2021-03-16:
Hi,

I am trying to compile your code, but I have encountered several problems:
(Fixed) Can't find pump.h (result downloaded from logic code)
(Fixed) Cannot find ADS1115 @ 1.0.0 from lib_deps (it generates an error that it cannot find the library ... but I have commented and downloaded it working)

Pending solution:
src \ Setup.cpp: 44: 4: error: aggregate 'tm timeinfo' has incomplete type and cannot be defined
  tm timeinfo;
     ^
Compiling .pio \ build \ serial_upload \ lib714 \ Easy Nextion Library \ readCustomCommands.cpp.o
*** [.pio \ build \ serial_upload \ src \ Setup.cpp.o] Error 1

You can help me?

Gixy31, 2021-03-16:
Hello,
Pump: https://github.com/Loic74650/PoolMaster
ADS1115: download it here: https://lygte-info.dk/project/ADS1115Library%20UK.html (not in GitHub)

Time and time is a long story... You have first to rename Time.h in _Time.h (Windows does'nt make difference between Time.h and time.h).

A new version is coming today, with a slightly modified timing of tasks in order to have a nice spreading of tasks along the cycle.

drivers1, 2021-03-16:
Hi, Thank you very much for your quick response.

I have tested on my macbook and I have the same problem (aggregate 'tm timeinfo' has incomplete type and cannot be defined).

Where I can find the file "Time.h" that I needs to change to "_Time.h"? Can test it on Mac or Windows. On both have the same problem.

Regards

Gixy31, 2021-03-17:
You should have a library called Time (paulstoffregen/Time @ 1.6). So in the folder of this library there's a header file called Time.h to rename in _Time.h. This folder is most probably in .pio/libdeps/serial_upload/Time, if you do not use the extra_libs folder in platformio.ini. The problem is that there is another header called time.h which is in the framework_arduinoespressif32 directory which must be included to declare the tm structure, but this Time.h file (which in turn includes time.h) put some garbage with the precompiler.

drivers1, 2021-03-17:
Solved!!! Thank you very much!!!

Other question. Could you share the file of the board "PoolMaster" you have designed? It would be good for me to know how are connected the sensors to esp32 and possibly to make one so that everything is more organized.

Regards!!

Gixy31, 2021-03-17:
OK. I'll do that later.
I close the issue.
Best Regards

Gixy31, 2021-03-22:
pdf of the board added to repository.

Closed 2021-03-17.

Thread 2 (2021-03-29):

Board

vaughnlfisher, 2021-03-29:
Where can i get my hands on the board

Gixy31, 2021-03-29:
Well, first by being polite, saying at least hello, please or something like that, which seems to be ignored by new generations... And second there is a pdf file called PoolMaster.pdf at the root of the directory with a 3D view and the schematic.

vaughnlfisher, 2021-03-29:
>
>
> Well, first by being polite, saying at least hello, please or something like that, which seems to be ignored by new generations... And second there is a pdf file called PoolMaster.pdf at the root of the directory with a 3D view and the schematic.
My question was rude so i appoloise.

I am not of the new generation even though i wish i was sometimes.

The pdf is a good representation. where could I get the board made? Have you had it made?

Thanks,

Gixy31, 2021-03-29:
I usualy have my boards made by JLCPCB, and yes this one is made and operational.

vaughnlfisher, 2021-03-30:
Hi
Do you have a Gerber file for me please? JLPCB is asking for one?
Thanks again!

Gixy31, 2021-03-30:
zip file added. Enjoy.

vaughnlfisher, 2021-03-30:
Thanks 🙏

Regards
Vaughn
Fisher

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

drivers1, 2021-03-30:
I'm interested too... Thanks very much!!!
One question. Are you order in JLPCB with option SMT Assembly??
Regards

Gixy31, 2021-03-31:
@drivers1
No, I do it by myself. SMD are big enough to be soldered by hand, with a binocular to help.

Closed 2021-03-29.

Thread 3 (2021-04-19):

BOM

vaughnlfisher, 2021-04-19:
Sorry to bother again!
Total newbee here!
Got the PCB's they worked a treat.
Struggling to find the correct resistor components to fit, hence the request for BOM?
Would also like to know what level sensors you used for the chlorine and acid solutions?

Thanks again!
V

Gixy31, 2021-04-28:
BoM file added.

kifeo, 2023-05-25:
Hello,

Thanks for your work on this !
While getting the items from the BOM, I've found out that most of the links are not directing me to the correct items.

Would it be possible to update the BOM ?

Thanks !

Closed 2021-04-28.

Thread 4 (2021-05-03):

librairie ads1115

tiji2486, 2021-05-03:
A priori pas la bonne version de ads1115, elle ne veut pas s'installer :

Library Manager: Installing ADS1115 @ 1.0.0
Warning! Could not find the package with 'ADS1115 @ 1.0.0' requirements for your system 'windows_amd64'

j'ai celle ci :  https://github.com/jrowberg/i2cdevlib.git

Gixy31, 2021-05-03:
Non, il faut aller la chercher directement ici : https://lygte-info.dk/project/ADS1115Library%20UK.html
Je l'ai trouvée par hasard, mais elle est bien faite, et permet en particulier de fonctionner en asynchrone (on n'attend pas les conversions).

tiji2486, 2021-05-03:
ok merci, plus d'erreurs sur cette librairies

Closed 2021-05-03.

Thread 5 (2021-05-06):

Grafana Dashboard

vaughnlfisher, 2021-05-06:
Sorry to ask for help again

I import the json grafan file but no panels show up in the newly created dashboard.
Do you think I’ve done something wrong?
Any ideas?

Thanks

Gixy31, 2021-05-06:
Of course you have created an InfluxDB database, populated by the NodeRed flow also included...
I imagine that you understand the global functionning of the system:
- PoolMaster (ESP32) sends messages on MQTT topics to a MQTT broker;
- the broker transfer those messages to subscribers of the given topics, in this case the NodeRed flow;
- the flow processes the data and send measurement to the InfluxDB database;
- Grafana then periodically retrieves data from InfluxDB and display them on a dashboard.
That means that you have to set up MQTT broker, Nodered server and flow, InfluxDB database and grafana. Did you do all this?

Closed 2021-05-29.

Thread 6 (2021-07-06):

Tank volume "problem"

vaughnlfisher, 2021-07-06:
Hi

Very good project my system is up and running, plus or minus. I have an issue potentially where the tank fill volume drops to zero in one movement. I dont understand why?

See attached picture of Grafan. Top panel show where over time ive set the tanks to 100% and randomly they drop to zero %

Any ideas?
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

Gixy31, 2021-07-06:
Hi,
Looking at pumps activities or ORP value, your system looks a bit strange. If you've modified the sofware, I can't help without seeing the code. I don't have this problem at all. The last version of my sofware has some modifications in the pump library and in the code to manage tank levels. May be you can try this new version.

vaughnlfisher, 2021-07-06:
Hi

I’ve not changed anything. Which specific files are you referring to? I have updated the settings etc but not code.

Thanks again

Gixy31, 2021-07-06:
Your pumps graph should look like this one. Did you set values in liters/min for the pH and chlorine pumps?
I encourage you to take the last version of the code and review your settings.
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

vaughnlfisher, 2021-07-06:
Thanks a million
I would expect the same graph as you. My graph suggests nothing is chinging in terms of the chlorine or ph pumps i.e. they stay off. If they stay off surely the tank should stay at 100%? I would expect a constant 100% on the tanks. Im testing outside of the pool environemt to make sure everything is good before i connect to the pool pipework.

vaughnlfisher, 2021-08-04:
Hi
I now have a pressure error at a 0.64 which I think is preventing any automatic dosing. My pump is not connected to the system, it’s independent. I have not modified any code.
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

vaughnlfisher, 2021-08-04:
thanks for your help
![Uploading D8EDD94E-EA69-4F35-876F-723C484EFB61.jpeg…]()

Hi changed it in the code, there is no where to set the medium threshold in node red. Still same problem?

Gixy31, 2021-08-04:
Normally there is one, called WPr Low in the settings dashboard (which is a more appropriate name).

vaughnlfisher, 2021-08-04:
Definitely nothing like that.
![Uploading F0DD7F4A-DA2E-49CB-A510-254E7D9FC501.jpeg…]()

vaughnlfisher, 2021-08-04:
Hi

I don’t see anything like that?
Maybe I’ve done something wrong?

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

Sorry for being a bother

Gixy31, 2021-08-05:
Yes, this is the original Nodered dashboard. I modified it a lot since that. It is not so hard to add more fields such as Water Pressure  medthreshold, and you can then learn a lot on how Nodered works :-)

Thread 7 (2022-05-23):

Buy HARDWARE for esp32-poolmaster

zhivko, 2022-05-23:
Hi is it possible to buy hardware somewhere or at least buy pcbs somewhere?
Have you built board and it has been put in work somewhere or is this hypothetical?

Gixy31, 2022-05-23:
Hi,
The gerber files used to build the PCB are in the zip file in the Code section. This is a real project running for 18 months now. More discussion and pictures here : https://forum.arduino.cc/t/poolmaster-gestion-et-domotisation-de-ma-piscine/563058/624 (sorry, in french).

Closed 2022-05-23.

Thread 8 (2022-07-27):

Gerber files

ippodrome, 2022-07-27:
Hi!
Thank you for this fork!

I’m having some issues with the pcb when it’s was sent to the pcb-maker.

they sent me this:

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

i have no idea what this means or how to fix it. What should I do?

Thank you! / viktor

Gixy31, 2022-07-27:
Hi,
Both are valid: the circles on the GKO layer ( Keep-out layer) are used to avoid traces routing too close from the holes. This is used only during PCB design. You can answer to your manufacturer to keep only drill holes and discard GKO layer.

ippodrome, 2022-07-27:
Thank you very much for the quick reply! 👏🏼
Will tell them!
😊

Closed 2022-07-27.

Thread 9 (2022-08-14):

Software doesn't publish any MQTYT

vaughnlfisher, 2022-08-14:
Hi

I have recently lost all my original code! I have been trying to get the system back up and running with your latest code.
The nexion screen works and is reporting Realtime data. I can also upload OTA so the WIFI is working.

Problem is no information in being published via MQTT. I have a subscription and monitoring the Topic.

Attached terminal screen, nothing seems to happen after the Subscibe ack. qos:2

Could you assist

rst:0x1 (POWERON_RESET),boot:0x13 (SPI_FAST_FLASH_BOOT)
configsip: 0, SPIWP:0xee
clk_drv:0x00,q_drv:0x00,d_drv:0x00,cs0_drv:0x00,hd_drv:0x00,wp_drv:0x00
mode:DIO, clock div:2
load:0x3fff0030,len:1184
load:0x40078000,len:13132
load:0x40080400,len:3036
entry 0x400805e4
[ 60 ] CPU frequency       : 240MHz
[ 61 ] CPU Cores           : 2
[ 61 ] Flash size          : 4MB
[ 61 ] Free RAM            : 282444 bytes
[ 72 ] Min heap            : 238072 bytes
[ 72 ] tskIDLE_PRIORITY    : 0
[ 72 ] confixMAX_PRIORITIES: 25
[ 72 ] configTICK_RATE_HZ  : 1000
[ 1396 ] Stored version: 51
[ 1397 ] Same version: 51 / 51. Loading settings from NVS
[ 1428 ] 51
[ 1428 ] 0, 0, 1, 0
[ 1429 ] 10, 10, 20, 8, 22, 20
[ 1429 ] 2700, 2700, 30000
[ 1429 ] 1800000, 1800000, 0, 0
[ 1429 ] 7.3,  720, 15.0, 15.0,  10,  18,  3.0, 3.496258, -2.011338, -876.430775, 2328.898500, 1.0, 0.0
[ 1440 ]  2700000,   0,   0,  18000,   0,   0,       0,       0, 28.00, 7.30,  720, 1.30
[ 1451 ]  60,  85,  20,  20, 1.5, 1.5
[ 1451 ] Config loaded
[ 1453 ] [WiFi] Connecting to WiFi...
[ 1631 ] [WiFi] Connection lost
[ 1716 ] [WiFi] Connected to: Fisher
[ 1716 ] [WiFi] IP address: 192.168.0.216
[ 1716 ] [WiFi] Hostname: PoolMaster
[ 1716 ] [WiFi] Connecting to MQTT...
[ 1760 ] Connected to MQTT, present session: 0
[ 1772 ] Subscribe ack., qos: 2
[ 2295 ] NTP configured
Sunday, August 14 2022 09:31:03
[ 2296 ] 2022/08/14 09:31:03
[ 2407 ] 1wire W devices: 1 device(s) found
[ 2408 ] 1wire A devices: 1 device(s) found
DS18B20_W: 28:a5:3f:8d:0c:00:00:bd
DS18B20_A: 28:aa:87:87:48:14:01:d5
[ 2530 ] Init done, starting loop tasks
[ 3631 ] [WiFi] Connecting to WiFi...
[ 3638 ] Disconnected from MQTT
[ 3661 ] [WiFi] Connection lost
[ 3802 ] [WiFi] Connected to: Fisher
[ 3803 ] [WiFi] IP address: 192.168.0.216
[ 3803 ] [WiFi] Hostname: PoolMaster
[ 3803 ] [WiFi] Connecting to MQTT...
[ 3840 ] Connected to MQTT, present session: 0
[ 3850 ] Subscribe ack., qos: 2
[ 5662 ] [WiFi] Connecting to WiFi...
[ 5668 ] Disconnected from MQTT
[ 5692 ] [WiFi] Connection lost
[ 5798 ] [WiFi] Connected to: Fisher
[ 5798 ] [WiFi] IP address: 192.168.0.216
[ 5798 ] [WiFi] Hostname: PoolMaster
[ 5798 ] [WiFi] Connecting to MQTT...
[ 5847 ] Connected to MQTT, present session: 0
[ 5855 ] Subscribe ack., qos: 2
[ 7692 ] [WiFi] Connecting to WiFi...
[ 7698 ] Disconnected from MQTT
[ 7722 ] [WiFi] Connection lost
[ 7827 ] [WiFi] Connected to: Fisher
[ 7827 ] [WiFi] IP address: 192.168.0.216
[ 7828 ] [WiFi] Hostname: PoolMaster
[ 7828 ] [WiFi] Connecting to MQTT...
[ 7884 ] Connected to MQTT, present session: 0
[ 7892 ] Subscribe ack., qos: 2
[ 9723 ] [WiFi] Connecting to WiFi...
[ 9729 ] Disconnected from MQTT
[ 9753 ] [WiFi] Connection lost
[ 10059 ] [WiFi] Connected to: Fisher
[ 10060 ] [WiFi] IP address: 192.168.0.216
[ 10060 ] [WiFi] Hostname: PoolMaster
[ 10060 ] [WiFi] Connecting to MQTT...
[ 10111 ] Connected to MQTT, present session: 0
[ 10117 ] Subscribe ack., qos: 2
[ 11753 ] [WiFi] Connecting to WiFi

Gixy31, 2022-08-14:
Hi,
Difficult to help from here, but according to the traces it seems you have a lot of WiFi disconnections, so MQTT disconnects as well.

vaughnlfisher, 2022-08-14:
Why would that be?

vaughnlfisher, 2022-08-14:
The WIFI is stable enough to do OTA.

Gixy31, 2022-08-14:
There are clearly WiFi events, but the traces are not in a logical order: should be 'connection lost' first, then 'connecting to wifi' and not the contrary.  Did you change the reconnect timers values (2000ms)? Another suggestion: try to update ESP32 Arduino core in PlatformIO.

Closed 2022-09-03.

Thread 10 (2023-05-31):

BOM obsolete

kifeo, 2023-05-31:
Hello,

Thanks for your work on this !
While getting the items from the BOM, I've found out that most of the links are not directing me to the correct items.

Would it be possible to update the BOM ?

Thanks !

kifeo, 2023-05-31:
It could be nice to be able to buy a package where you get some $$ percentage of it !

Gixy31, 2023-05-31:
Hum, remember that it is a DIY project, not a commercial one. It would be an endless work to continuously update the BOM from sellers like Amazon or AliExpress. Nevertheless, with the description of each component in the BOM, and with the pictures and schematics, I have no doubt that you can find everything to build the project. And then feel free to create a kit package.

Closed 2023-05-31.

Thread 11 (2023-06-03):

Bug possible en utilisant la lib ADS1115

shibida, 2023-06-03:
A cet endroit là :
https://github.com/Gixy31/ESP32-PoolMaster/blob/79e7cb5b6e01c8f416d057ba21296b8ecd581c4a/src/Loops.cpp#L78

Tu ne te sers pas du résultat de la fonction adc.update().
Juste en dessous tu viens lire adc.ready(), qui peut entre temps, avoir terminé, et donc tu peux lire potentiellement des valeurs qui sont fausses.

Je pense que si tu mets adc.update dans ton if, ça corrige éventuellement un bug.

Pour ma part je vais fork et utiliser une librairie plus standard pour ADS, d'autant plus que la seule fonction qui n'y est pas est les valeurs moyennes que tu reimplementes un peu plus loin. Peut être une autre fois je me servirait des signaux ready pour faire du vrai asynchrone avec les interruptions.

Si tu veux tu prendras la pool request.

Gixy31, 2023-06-03:
???
Il faut lire la doc de la librairie : adc.update est un void, donc ne produit pas de résultat. Cette fonction doit être appelée à un rythme supérieur à la vitesse de conversion et sert à relancer les conversions entre chaque canal. Lorsque toutes les conversions sont terminées, c'est adc.ready qui le confirme. Donc ce code est correct et parfaitement conforme à ce qu'il faut faire tel que décrit dans la doc.

Gixy31, 2023-06-03:
Et si tu déplaces adc.update() dans le if, adc.ready() ne sera jamais true et donc...

shibida, 2023-06-03:
Oui, je suis d'accord avec toi si on lit la doc ! Mais regarde mieux le code de la lib.
dans le .h l133 ou même dans le code cpp c'est un bool en fait.

De plus la variable "done" n'est protégée nulle part ...

Le risque est faible mais il est bien là.

Gixy31, 2023-06-03:
Je ne comprends pas de quel risque tu parles...

Le boolean done de la classe est private donc ne risque rien. Ensuite c'est bien update() qui relance une à une les conversions sur les canaux sélectionnés. Si tu appelles ready() sans avoir fait update(), tu n'auras jamais rien.
Donc je persiste :
On fait update() plus vite que la vitesse de conversion, ce qui permet de relancer une conversion après que chaque canal soit fait. Lorsque toutes les conversions sont faites, done passe à true et ready() (qui n'est que la version publique de done) permet de venir récupérer les valeurs et on repart pour un cycle.

Sans trop approfondir, je pense qu'on pourrait se contenter de if adc.update() puisque'en effet update() renvoie done et ne pas utiliser ready(). Mais en tous cas déplacer update() derrière le test de ready() ne peut pas fonctionner.

Cette fonction update() permet justement de ne pas se préoccuper de la fin de toutes les conversions avant de lire les valeurs, alors que les autres librairies, même en asynchrone,  obligent à gérer soi-même la boucle sur les 4 canaux.

shibida, 2023-06-03:
Bon ok désolé du bruit, j'ai mélangé le done de cette classe avec une autre lib qui utilise les meme nom de variable.

Bref pas de bug mais une doc pas à jour ...

Closed 2023-06-03.

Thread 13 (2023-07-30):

Erreur de compilation Olimex ESP32-EVB.

Fouggee, 2023-07-30:
Bonjour,

J'essai de compiler ESP32-PoolMaster sur un Olimex ESP32-EVB. La compilation échoue avec pluseurs erreurs concernant ADS1115 :

Library Manager: Installing ADS1115 @ 1.0.0
Warning! Could not find the package with 'ADS1115 @ 1.0.0' requirements for your system 'windows_amd64'

Alors plusieurs erreurs sortent du fichier src/Loops.cpp :

src/Loops.cpp:16:8: error: 'ADS1115Scanner' does not name a type; did you mean 'ADS1115'?
src/Loops.cpp:44:3: error: 'adc' was not declared in this scope
src/Loops.cpp:44:16: error: 'ADS1115_SPEED_16SPS' was not declared in this scope
etc ...

Peut-être avez-vous une idée?

Merci,
Jérôme.

Ci-dessous le résultat de la compilation dans le moniteur :

Processing serial_upload (platform: espressif32; board: esp32-evb; framework: arduino)
--------------------------------------------------------------------------------------------------------------------------------
Verbose mode can be enabled via `-v, --verbose` option
CONFIGURATION: https://docs.platformio.org/page/boards/espressif32/esp32-evb.html
PLATFORM: Espressif 32 (6.3.2) > OLIMEX ESP32-EVB
HARDWARE: ESP32 240MHz, 320KB RAM, 4MB Flash
DEBUG: Current (esp-prog) External (cmsis-dap, esp-bridge, esp-prog, iot-bus-jtag, jlink, minimodule, olimex-arm-usb-ocd, olimex-arm-usb-ocd-h, olimex-arm-usb-tiny-h, olimex-jtag-tiny, tumpa)
PACKAGES:
 - framework-arduinoespressif32 @ 3.20009.0 (2.0.9)
 - tool-esptoolpy @ 1.40501.0 (4.5.1)
 - tool-openocd-esp32 @ 2.1100.20220706 (11.0)
 - toolchain-xtensa-esp32 @ 8.4.0+2021r2-patch5
LDF: Library Dependency Finder -> https://bit.ly/configure-pio-ldf
LDF Modes: Finder ~ chain+, Compatibility ~ soft
Library Manager: Installing ADS1115 @ 1.0.0
Warning! Could not find the package with 'ADS1115 @ 1.0.0' requirements for your system 'windows_amd64'
Found 47 compatible libraries
Scanning dependencies...
Dependency Graph
|-- Arduino_DebugUtils @ 1.1.0
|-- Time @ 1.6.1
|-- PID @ 1.2.1
|-- I2Cdevlib-ADS1115 @ 1.0.0
|-- RunningMedian @ 0.2.1
|-- ArduinoJson @ 6.21.3
|-- Easy Nextion Library @ 1.0.6
|-- DallasTemperature @ 3.11.0
|-- AsyncTCP @ 1.1.1
|-- AsyncMqttClient @ 0.8.2
|-- OneWire @ 2.3.7
|-- Wire @ 2.0.0
|-- Pump-master
|-- Preferences @ 2.0.0
|-- WiFi @ 2.0.0
|-- ESPmDNS @ 2.0.0
|-- ArduinoOTA @ 2.0.0
|-- Update @ 2.0.0
|-- I2Cdevlib-Core @ 1.0.1
Building in debug mode
Compiling .pio\build\serial_upload\src\Loops.cpp.o
Compiling .pio\build\serial_upload\src\Nextion.cpp.o
Compiling .pio\build\serial_upload\src\PoolMaster.cpp.o
Compiling .pio\build\serial_upload\src\PoolServer.cpp.o
src/Loops.cpp:16:8: error: 'ADS1115Scanner' does not name a type; did you mean 'ADS1115'?
 static ADS1115Scanner adc(0x48);  // Address 0x48 is the default
        ^~~~~~~~~~~~~~
        ADS1115
src/Loops.cpp: In function 'void AnalogInit()':
src/Loops.cpp:44:3: error: 'adc' was not declared in this scope
   adc.setSpeed(ADS1115_SPEED_16SPS);
   ^~~
src/Loops.cpp:44:16: error: 'ADS1115_SPEED_16SPS' was not declared in this scope
   adc.setSpeed(ADS1115_SPEED_16SPS);
                ^~~~~~~~~~~~~~~~~~~
src/Loops.cpp:44:16: note: suggested alternative: 'ADS1115_RATE_16'
   adc.setSpeed(ADS1115_SPEED_16SPS);
                ^~~~~~~~~~~~~~~~~~~
                ADS1115_RATE_16
src/Loops.cpp:45:18: error: 'ADS1115_CHANNEL0' was not declared in this scope
   adc.addChannel(ADS1115_CHANNEL0, ADS1115_RANGE_6144);
                  ^~~~~~~~~~~~~~~~
src/Loops.cpp:45:18: note: suggested alternative: 'ADS1115_RATE_8'
   adc.addChannel(ADS1115_CHANNEL0, ADS1115_RANGE_6144);
                  ^~~~~~~~~~~~~~~~
                  ADS1115_RATE_8
src/Loops.cpp:45:36: error: 'ADS1115_RANGE_6144' was not declared in this scope
   adc.addChannel(ADS1115_CHANNEL0, ADS1115_RANGE_6144);
                                    ^~~~~~~~~~~~~~~~~~
src/Loops.cpp:45:36: note: suggested alternative: 'ADS1115_RATE_64'
   adc.addChannel(ADS1115_CHANNEL0, ADS1115_RANGE_6144);
                                    ^~~~~~~~~~~~~~~~~~
                                    ADS1115_RATE_64
src/Loops.cpp:46:18: error: 'ADS1115_CHANNEL1' was not declared in this scope
   adc.addChannel(ADS1115_CHANNEL1, ADS1115_RANGE_6144);
                  ^~~~~~~~~~~~~~~~
src/Loops.cpp:46:18: note: suggested alternative: 'ADS1115_RATE_16'
   adc.addChannel(ADS1115_CHANNEL1, ADS1115_RANGE_6144);
                  ^~~~~~~~~~~~~~~~
                  ADS1115_RATE_16
src/Loops.cpp:47:18: error: 'ADS1115_CHANNEL2' was not declared in this scope
   adc.addChannel(ADS1115_CHANNEL2, ADS1115_RANGE_6144);
                  ^~~~~~~~~~~~~~~~
src/Loops.cpp:47:18: note: suggested alternative: 'ADS1115_RATE_32'
   adc.addChannel(ADS1115_CHANNEL2, ADS1115_RANGE_6144);
                  ^~~~~~~~~~~~~~~~
                  ADS1115_RATE_32
src/Loops.cpp: In function 'void AnalogPoll(void*)':
src/Loops.cpp:67:3: error: 'adc' was not declared in this scope
   adc.start();
   ^~~
*** [.pio\build\serial_upload\src\Loops.cpp.o] Error 1
================================================= [FAILED] Took 20.69 seconds =================================================

Environment    Status    Duration
-------------  --------  ------------
serial_upload  FAILED    00:00:20.688
============================================ 1 failed, 0 succeeded in 00:00:20.688 ============================================

 *  The terminal process "C:\Users\xxxxxxx\.platformio\penv\Scripts\platformio.exe 'run'" terminated with exit code: 1.
 *  Terminal will be reused by tasks, press any key to close it.

Gixy31, 2023-07-31:
Bonjour,
Les messages sont pourtant clairs : vous n’avez pas installé la librairie ADS1115. Celle-ci n’est pas dans le registre général de PlatformIO et doit être installée manuellement. Le source est ici : https://lygte-info.dk/project/ADS1115Library%20UK.html
L'emplacement où vous installez la librairie doit figurer dans le fichier platformio.ini du projet (symlink).

Fouggee, 2023-07-31:
Bonsoir,

Merci pour la mise à jour.
Avec le Symlink la compilation fonctionne.
Pour les nouveaux sur platformio il serait bien de l'ajouter dans le readme ou directement en commentaire dans le fichier platformio.ini.

Cordialement,
Jérôme

Gixy31, 2023-07-31:
Commentaire ajouté dans platformio.ini

Closed 2023-07-31.

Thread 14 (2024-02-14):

CAD/Eagle File

aaronweaver, 2024-02-14:
Thanks for putting the project on github and supplying the code and documentation. Would it be possible to also upload the eagle/CAD file as well? I wanted to make a couple slight modifications on the board. Thanks!

Gixy31, 2024-02-14:
Hi,
I don’t use Eagle but Altium. Let me know if you can import Altium files and I will upload them.

Envoyé à partir de Courrier pour Windows

De : Aaron Weaver
Envoyé le :mercredi 14 février 2024 17:49
À : Gixy31/ESP32-PoolMaster
Cc : Subscribed
Objet :[Gixy31/ESP32-PoolMaster] CAD/Eagle File (Issue #14)

Thanks for putting the project on github and supplying the code and documentation. Would it be possible to also upload the eagle/CAD file as well? I wanted to make a couple slight modifications on the board. Thanks!
—
Reply to this email directly, view it on GitHub, or unsubscribe.
You are receiving this because you are subscribed to this thread.Message ID: ***@***.***>

aaronweaver, 2024-02-14:
Yes I can import Altium files. Thanks again!

Gixy31, 2024-02-14:
Files uploaded, enjoy!

Envoyé à partir de Courrier pour Windows

De : Aaron Weaver
Envoyé le :mercredi 14 février 2024 19:07
À : Gixy31/ESP32-PoolMaster
Cc : Gixy31; Comment
Objet :Re: [Gixy31/ESP32-PoolMaster] CAD/Eagle File (Issue #14)

Yes I can import Altium files. Thanks again!
—
Reply to this email directly, view it on GitHub, or unsubscribe.
You are receiving this because you commented.Message ID: ***@***.***>

Gixy31, 2024-02-21:
Request done

Closed 2024-02-21.

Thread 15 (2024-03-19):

Bom for the card does not exist.

jacquesj1, 2024-03-19:
Hello,
The gerber files exist but, is it possible to have the bom file associated ?

Thanks

jacquesj1, 2024-03-19:
Bonjour,
Super merci!
Je trouve votre projet très intéressant.
J'ai d'autres questions :
Avez-vous un schéma de connexion entre votre carte PoolMaster, les relais,
les pompes, .... ?
Comment intégrez- vous les chambres d'analyse ?

Encore bravo pour votre projet !
Cordialement,
Jérôme JACQUES

<https://www.avast.com/sig-email?utm_medium=email&utm_source=link&utm_campaign=sig-email&utm_content=webmail>
Sans
virus.www.avast.com
<https://www.avast.com/sig-email?utm_medium=email&utm_source=link&utm_campaign=sig-email&utm_content=webmail>
<#DAB4FAD8-2DD7-40BB-A1B8-4E2AA1F9FDF2>

Le mar. 19 mars 2024 à 15:39, Gixy31 ***@***.***> a écrit :

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

--
Jérôme JACQUES
Président Directeur
06-72-71-19-72
***@***.***

Gixy31, 2024-03-19:
Bonjour,
Pas de schéma global. Vous avez des photos ici : https://forum.arduino.cc/t/poolmaster-gestion-et-domotisation-de-ma-piscine/563058/350?u=gixy31
Je vous conseille de consulter le topic complet, certes plus de 1000 posts, mais vous devriez trouver réponses à beaucoup de question déjà posées sur les différentes versions du projet, dont je ne suis pas le concepteur initial comme indiqué en introduction.
Les sondes sont dans des chambres d'analyse en dérivation sur le circuit de filtration.
Les relais de la pompe de filtration, du surpresseur du robot et du projecteur activent des commutateurs dans l'armoire d'origine de la piscine, ce qui fait que les relais de PoolMaster ne coupent pas des courants forts mais seulement les bobines des commutateurs, elles-mêmes munies de snubbers pour éviter les parasites à la coupure. Les pompes peristaltiques sont directement reliées aux relais de PoolMaster car de faible puissance.

jacquesj1, 2024-03-20:
MERCI BEAUCOUP !

<https://www.avast.com/sig-email?utm_medium=email&utm_source=link&utm_campaign=sig-email&utm_content=webmail>
Sans
virus.www.avast.com
<https://www.avast.com/sig-email?utm_medium=email&utm_source=link&utm_campaign=sig-email&utm_content=webmail>
<#DAB4FAD8-2DD7-40BB-A1B8-4E2AA1F9FDF2>

Le mar. 19 mars 2024 à 16:45, Gixy31 ***@***.***> a écrit :

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

--
Jérôme JACQUES
Président Directeur
06-72-71-19-72
***@***.***

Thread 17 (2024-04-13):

Formules calcul pH orp psi

cloubier, 2024-04-13:
Bonjour
Peux tu partager du détails sur les formules de calcul ?

Gixy31, 2024-04-13:
Ben, rien de sorcier. Avec le setup de l'ADS1115, on a 6,144 V pour 32767 en valeur binaire sur 15 bits, donc  en multipliant la valeur binaire par 0.1875/1000 on obtient les volts (0,1875/1000 c'est pareil que 6.144/32768) . Ensuite on fait l'étalonnage des sondes dans les solutions étalons et on transforme les Volts en pH ou mv d'Orp. Pour la pression, j'ai un manomètre sur le circuit d'eau qui me permet d'étalonner la mesure.
On pourrait éviter le passage par les volts et passer directement de la valeur binaire à la valeur physique, mais quand on fait la mise au point du circuit, cela permet de valider la mesure avec un voltmètre à l'entrée du convertisseur ADS1115.

Closed 2024-04-13.

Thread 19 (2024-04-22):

Installation

ippodrome, 2024-04-22:
Hi!
Is there any documentation on how to install this software and set it up?
Im new to platformIO but have managed to install it and connect to the ESP32 but then I'm quite lost.
Where do I setup my wifi settings and how do i connect to the board when installed?

Thanks!

Gixy31, 2024-04-22:
Look at config.h and platormio.ini. Learn more about platformio and experiment by yourself. I cannot make this for you.

ippodrome, 2024-04-24:
Thank you for replying. Will try to learn! :P

Closed 2024-04-22.

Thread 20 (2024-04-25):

No probe readings

REDDE4D, 2024-04-25:
Hello i am currently in the process of recreating this awesome Project for my Pool.

Everything but the probes functions. I get readings of pH 40.4 and ORP of -897mV
I tried running an I2C scanner but it only finds the address 0x38 wich should be the PCF8574A.
The ADS1115 wich should have an address of 0x48 is not found. 
I checked all physical connections and checked the voltages of the components even used a new mcu but still no luck.

Does someone have or had a simular problem?

Gixy31, 2024-04-25:
Hi,
What do you mean by "recreating"? Do you use my board or one of your own?

Did you see that there is now two options for probes connection: INT_ADS1115 which uses the ADS1115 of the mother-board, and EXT_ADS1115 which uses a dedicated pH_Orp board with its own ADS1115, whose address should not be the same than the other one which is only used for water pressure in this case. The configuration is defined in config.h and I'm afraid that at the moment it is defined as EXT_ADS1115, so the software is looking for address 0x49.

0x48 is the address of the ADS1115 if you wired it with the address pin to GND. Did you checked the ADS1115 itself: if it is not found, may be it is the culprit.

Are those readings obtained with the probes into the water? Are you sure of the probes wiring?

How are the probes connected: Phydget boards or something else? Try to disconnect the probes (AN0, AN1), inject some known analog voltage between 0 and 5V and activate DBG_DEBUG mode to see traces and validate the measurement chain.

Well, lot of questions, but difficult to help without knowing anything of your configuration.

REDDE4D, 2024-04-25:
Sorry recreating may be a wrong term. Im use your board design.
In the config the connection option is set to INT\_ADS1115.
The probes are connected via the Phydget adapter and the dfrobot gravity isolators and sitting in an calibration fluid while meassuring.
Applying an voltag of 4V to A0 and A1 didn't result in a change. It seems like the ADS1115 might be the problem as it infact didn't get picked up by the i2c scanner. I ordered some replacements that get deliverd tomorrow so i need to check back then.

I'll let you know if i have any updates. Thanks for your help so far and keep up the awesome work :)

Cheers

REDDE4D, 2024-04-26:
Hey,

just a quick update. It infact was a dead ADS1115. Replaced it and now everything works like a charm.
Thanks again for you help and have a nice weekend.

Cheers

Gixy31, 2024-04-26:
:-)

REDDE4D, 2024-04-27:
One simple question I have left is about the calibration of the pH probe. Does the calibrated values survive a reboot or possible reflash?
Or do I have to recalibrate each time?

Gixy31, 2024-04-27:
When you calibrate the probes , the coefficients are updated in EEPROM and so they "survive" reboot and/or reflash. They're only replaced if you change CONFIG_VERSION in config.h, where they take the values defined in setup.cpp

Closed 2024-04-26.

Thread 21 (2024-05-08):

Calibration of Pressure Sensor

REDDE4D, 2024-05-08:
Hey,
does anyone know a good way to calibrate the pressure sensor?
I'm using this Sensor: https://amzn.eu/d/ekGDIym

It shows -0.9 on the display and doesn't change when the pump is running.
The manual gauge shows around 0.5bar when the pump is running.

Looking at the mqtt values they report as follows
Pump Off: -9.3122074991 PSI
Pump On after 15 min: -8.752225019 PSI

Thanks in advance

Gixy31, 2024-05-08:
You shouldn't have negative values. 0.5 bar when the pump is running is very low, usually it is between 0.8 and 1.5 bar. MQTT values should be the same than displayed. So activate traces and debug...

Closed 2024-05-08.

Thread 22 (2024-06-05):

LED State

csc-solution, 2024-06-05:
Hi,

is there a little description, which led is for what state? I couldn't find it in the readme files.

Thanks in advance

Kind regards,
Tom

Gixy31, 2024-06-06:
Hi,I dont remember if there is something like that but you can have a look to the code loops.cpp Le 5 juin 2024 03:32, csc-solution ***@***.***> a écrit :
Hi,
is there a little description, which led is for what state? I couldn't find it in the readme files.
Thanks in advance
Kind regards,
Tom

—Reply to this email directly, view it on GitHub, or unsubscribe.You are receiving this because you are subscribed to this thread.Message ID: ***@***.***>

csc-solution, 2024-06-06:
Thanks a lot.

Closed 2024-06-06.

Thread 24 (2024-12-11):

Pick Place for main board

vaughnlfisher, 2024-12-11:
Hi

It's me again :)

Could i get the pick place file for the main board please?

Thanks!

Gixy31, 2024-12-11:
Hi,
There is not P&P file as there are modules on the board (Power supply, ADS1115, level shifter, ESP32_DevKit) that are surely not available in the component store of the manufacturer. I think you have better to populate the board by yourself, it's not difficult, with only a few SMD LEDs and resistors , everything else is thru hole.
Regards

Closed 2024-12-11.

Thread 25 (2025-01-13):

kicad files for the v2 orp/ph board

henjo, 2025-01-13:
Hi,

I would like to build a ORP/PH board with a different pitch of the BNC connectors. I like the layout of your version of the board and would rather base my board on your layout. Is it also designed with kicad, and if so would it be possible for you to publish the cad files?

Best regards,
Henrik

Gixy31, 2025-01-14:
Hi,
I'm sorry, but the board is designed with Altium, not Kicad. Anyway, I will publish the CAD files and you may convert the files.

Closed 2025-01-14.

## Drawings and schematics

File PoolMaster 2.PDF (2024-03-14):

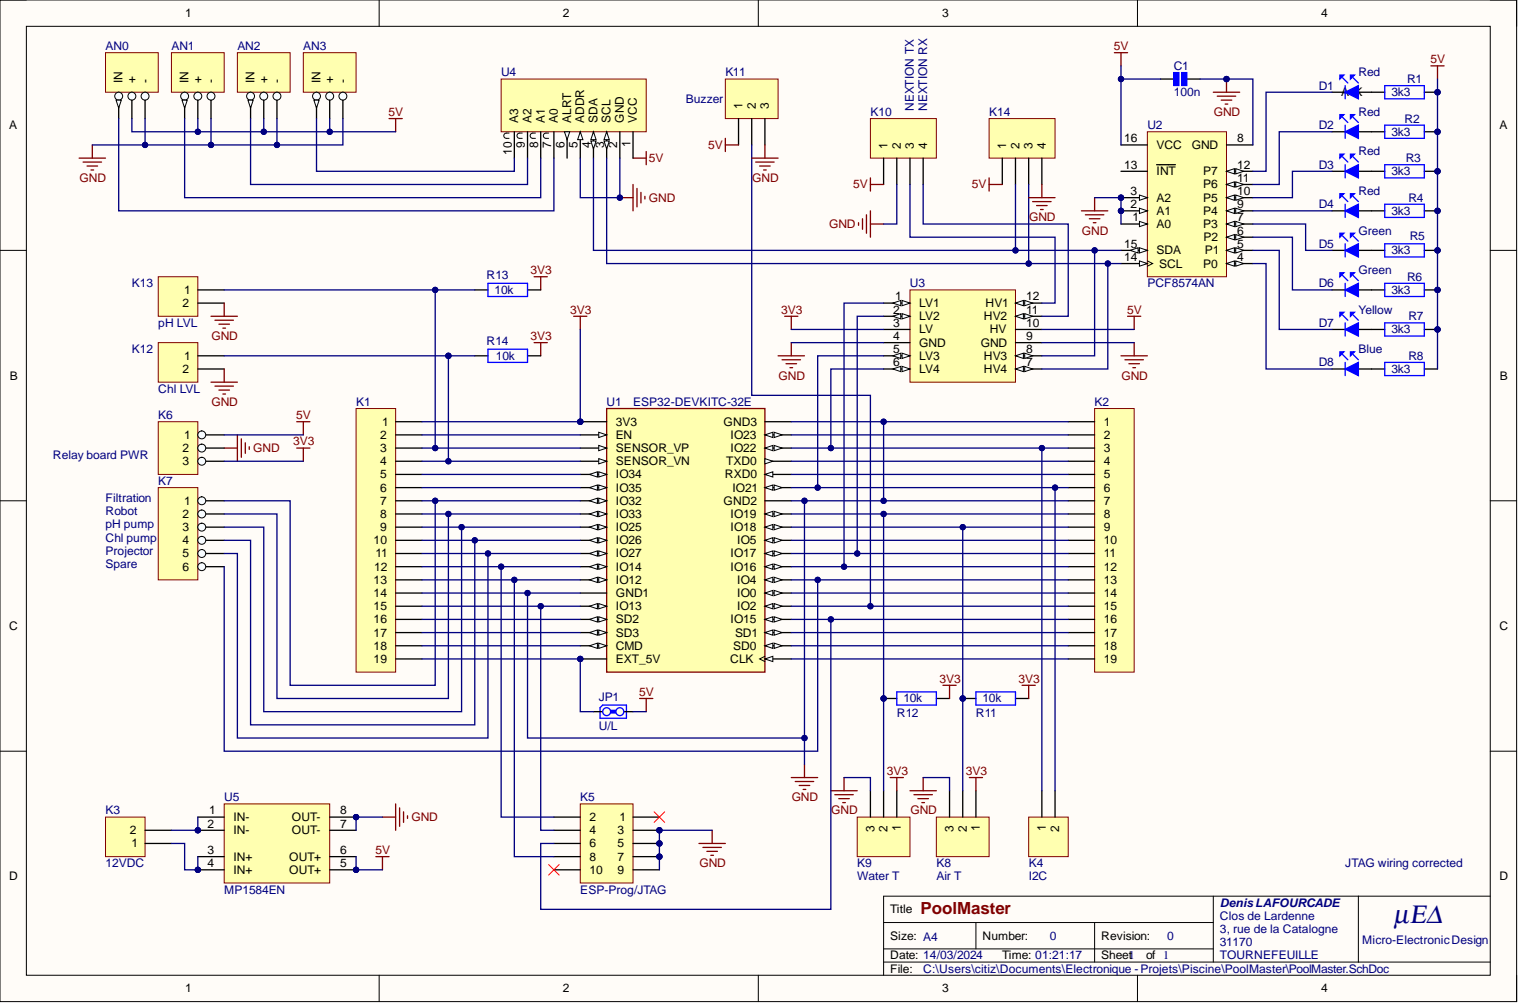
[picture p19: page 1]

VCC 1 GND 2 SCL 3 SDA 4 ADDR 5 ALRT 6 A0 7 A1 8 A2 9 A3 10 U4

8 | IO33 IO19 IO25 IO18 IO26 IO5 IO27 IO17 IO16
10
11
12
13 14 15 16 17 18 19 | | | IO4 IO0 IO2 SD2 IO15

SD3 SD1 CMD SD0 EXT_5V CLK

Denis LAFOURCADE
Clos de Lardenne
3, rue de la Catalogne

Date:
C:\Users\citiz\Documents\Electronique - Projets\Piscine\PoolMaster\PoolMaster.SchDoc
File:

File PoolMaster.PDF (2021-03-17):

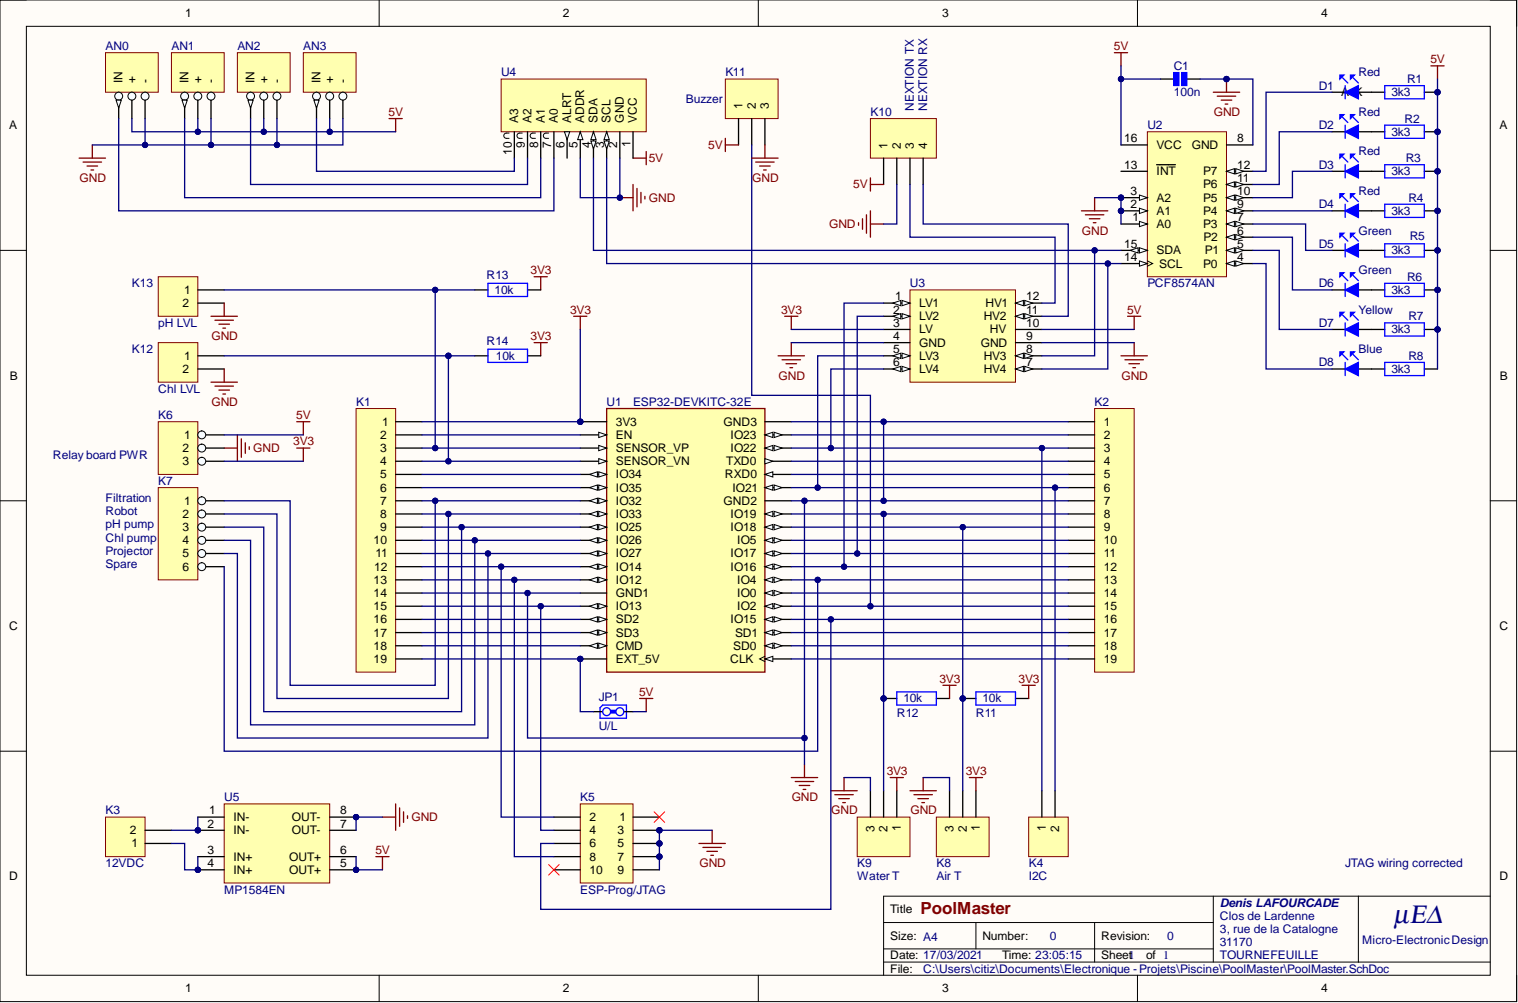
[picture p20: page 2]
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

5 | D 5
4 | | Green

2 | LV | | 1 1
3 | V LV H GN D GN D LV 3 H V 3 LV 4 H V 4 | 10

12
13 14 15 16 17 18 19 | | | SD 2 IO1 | 4 0

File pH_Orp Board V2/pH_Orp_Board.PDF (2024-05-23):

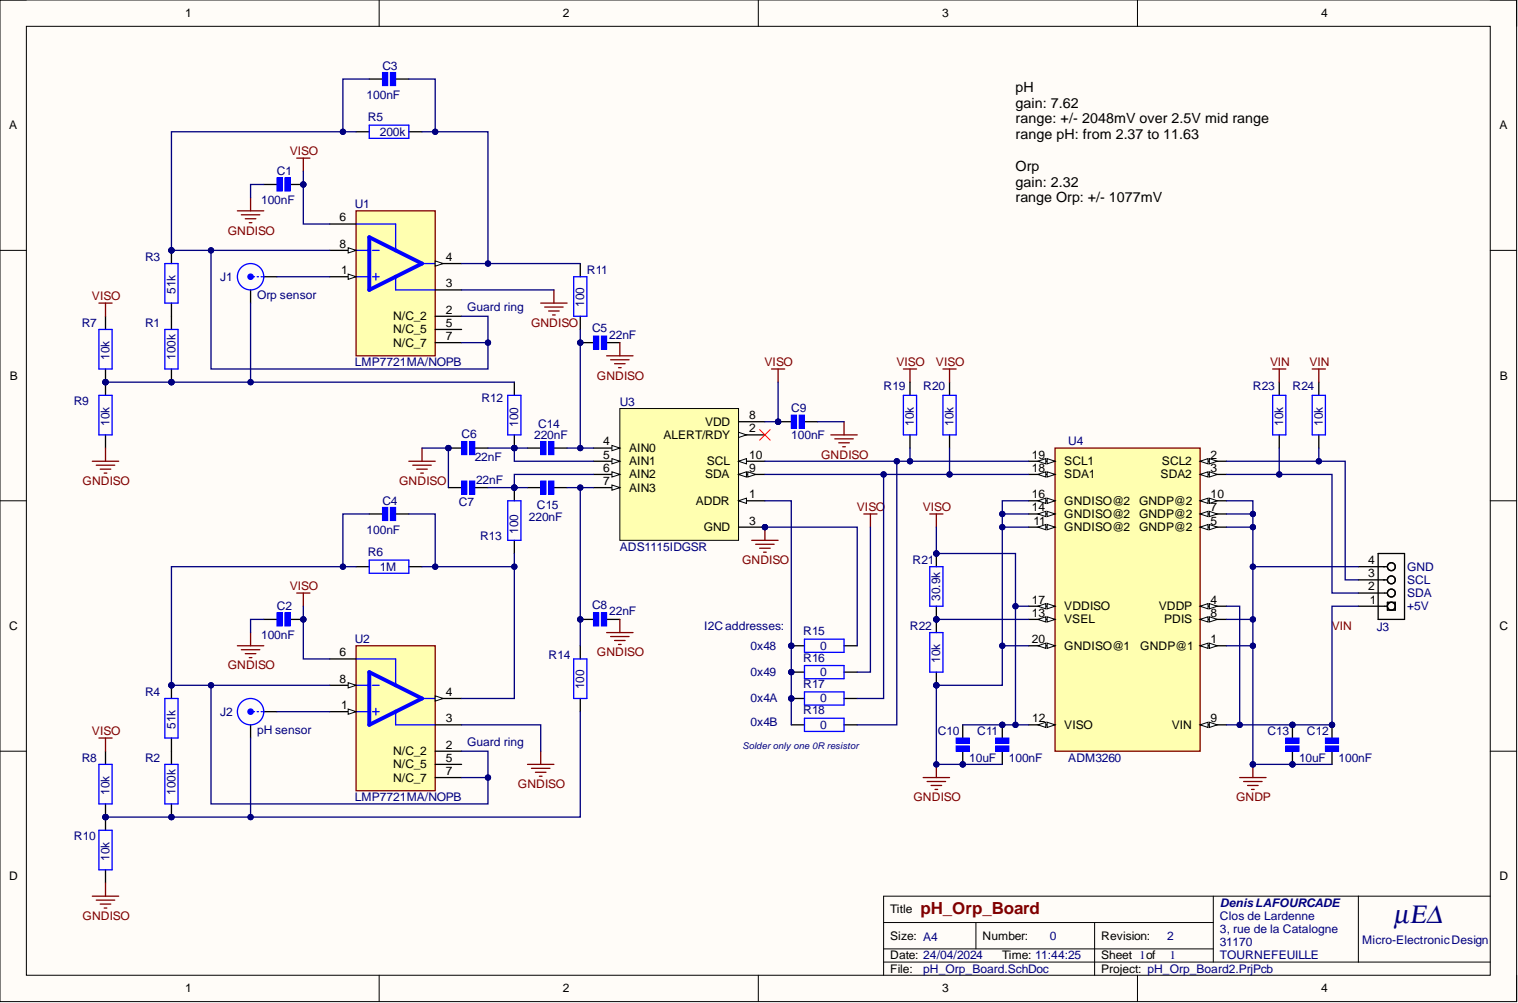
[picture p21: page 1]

range pH: from 2.37 to 11.63

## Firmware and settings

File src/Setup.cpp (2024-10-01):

#undef __STRICT_ANSI__              // work-around for Time Zone definition
#include <stdint.h>                 // std lib (types definitions)
#include <Arduino.h>                // Arduino framework
#include <esp_sntp.h>

#include "Config.h"
#include "PoolMaster.h"

#ifdef SIMU
bool init_simu = true;
double pHLastValue = 7.;
unsigned long pHLastTime = 0;
double OrpLastValue = 730.;
unsigned long OrpLastTime = 0;
double pHTab [3] {0.,0.,0.};
double ChlTab [3] {0.,0.,0.};
uint8_t iw = 0;
uint8_t jw = 0;
bool newpHOutput = false;
bool newChlOutput = false;
double pHCumul = 0.;
double ChlCumul = 0.;
#endif

// Firmware revision
String Firmw = FIRMW;

//Settings structure and its default values
// si pH+ : Kp=2250000.
// si pH- : Kp=2700000.
#ifdef EXT_ADS1115
StoreStruct storage =
{ 
  CONFIG_VERSION,
  0, 0, 1, 0,
  13, 8, 21, 8, 22, 20,
  2700, 2700, 30000,
  1800000, 1800000, 0, 0,
  7.3, 720.0, 1.8, 0.7, 10.0, 18.0, 3.0, -2.2183, 7.0, 431.03, 0.0, 1.31, -0.1,
  2700000.0, 0.0, 0.0, 18000.0, 0.0, 0.0, 0.0, 0.0, 28.0, 7.3, 720., 1.3,
  25.0, 60.0, 20.0, 20.0, 1.5, 1.5
};
#else
StoreStruct storage =
{ 
  CONFIG_VERSION,
  0, 0, 1, 0,
  12, 9, 21, 8, 22, 20,
  2700, 2700, 30000,
  1800000, 1800000, 0, 0,
  7.3, 650.0, 1.8, 0.7, 10.0, 18.0, 3.0, 3.61078313, -3.88020422, -966.946396, 2526.88809, 1.31, -0.1,
  2700000.0, 0.0, 0.0, 18000.0, 0.0, 0.0, 0.0, 0.0, 28.0, 7.3, 650., 1.3,
  50.0, 68.0, 20.0, 20.0, 1.5, 1.5
};
#endif

tm timeinfo;

// Various global flags
volatile bool startTasks = false;               // Signal to start loop tasks

bool AntiFreezeFiltering = false;               // Filtration anti freeze mode
bool EmergencyStopFiltPump = false;             // flag will be (re)set by double-tapp button
bool PSIError = false;                          // Water pressure OK
bool cleaning_done = false;                     // daily cleaning done   

// Queue object to store incoming JSON commands (up to 10)
QueueHandle_t queueIn;

// NVS Non Volatile SRAM (eqv. EEPROM)
Preferences nvs;      

// Instanciations of Pump and PID objects to make them global. But the constructors are then called 
// before loading of the storage struct. At run time, the attributes take the default
// values of the storage struct as they are compiled, just a few lines above, and not those which will 
// be read from NVS later. This means that the correct objects attributes must be set later in
// the setup function (fortunatelly, init methods exist).

// The four pumps of the system (instanciate the Pump class)
// In this case, all pumps start/Stop are managed by relays. pH, ORP and Robot pumps are interlocked with 
// filtration pump
Pump FiltrationPump(FILTRATION_PUMP, FILTRATION_PUMP);
Pump PhPump(PH_PUMP, PH_PUMP, NO_LEVEL, FILTRATION_PUMP, storage.pHPumpFR, storage.pHTankVol, storage.AcidFill);
Pump ChlPump(CHL_PUMP, CHL_PUMP, NO_LEVEL, FILTRATION_PUMP, storage.ChlPumpFR, storage.ChlTankVol, storage.ChlFill);
Pump RobotPump(ROBOT_PUMP, ROBOT_PUMP, NO_TANK, FILTRATION_PUMP);

// PIDs instances
//Specify the direction and initial tuning parameters
PID PhPID(&storage.PhValue, &storage.PhPIDOutput, &storage.Ph_SetPoint, storage.Ph_Kp, storage.Ph_Ki, storage.Ph_Kd, PhPID_DIRECTION);
PID OrpPID(&storage.OrpValue, &storage.OrpPIDOutput, &storage.Orp_SetPoint, storage.Orp_Kp, storage.Orp_Ki, storage.Orp_Kd, OrpPID_DIRECTION);

// Publishing tasks handles to notify them
static TaskHandle_t pubSetTaskHandle;
static TaskHandle_t pubMeasTaskHandle;

// Mutex to share access to I2C bus among two tasks: AnalogPoll and StatusLights
static SemaphoreHandle_t mutex;

// Functions prototypes
void StartTime(void);
void readLocalTime(void);
bool loadConfig(void);
bool saveConfig(void);
void WiFiEvent(WiFiEvent_t);
void initTimers(void);
void connectToWiFi(void);
void mqttInit(void);                     
void InitTFT(void);
void ResetTFT(void);
void PublishSettings(void);
void SetPhPID(bool);
void SetOrpPID(bool);
int  freeRam (void);
void AnalogInit(void);
void TempInit(void);
bool saveParam(const char*,uint8_t );
unsigned stack_hwm();
void stack_mon(UBaseType_t&);
void info();

// Functions used as Tasks
void PoolMaster(void*);
void AnalogPoll(void*);
void pHRegulation(void*);
void OrpRegulation(void*);
void getTemp(void*);
void ProcessCommand(void*);
void SettingsPublish(void*);
void MeasuresPublish(void*);
void StatusLights(void*);

// Setup
void setup()
{
  //Serial port for debug info
  Serial.begin(115200);

  // Set appropriate debug level. The level is defined in PoolMaster.h
  Debug.setDebugLevel(DEBUG_LEVEL);
  Debug.timestampOn();
  Debug.debugLabelOn();
  Debug.formatTimestampOn();

  //get board info
  info();
  
  // Initialize Nextion TFT
  InitTFT();
  ResetTFT();

  //Read ConfigVersion. If does not match expected value, restore default values
  if(nvs.begin("PoolMaster",true))
  {
    uint8_t vers = nvs.getUChar("ConfigVersion",0);
    Debug.print(DBG_INFO,"Stored version: %d",vers);
    nvs.end();

    if (vers == CONFIG_VERSION)
    {
      Debug.print(DBG_INFO,"Same version: %d / %d. Loading settings from NVS",vers,CONFIG_VERSION);
      if(loadConfig()) Debug.print(DBG_INFO,"Config loaded"); //Restore stored values from NVS
    }
    else
    {
      Debug.print(DBG_INFO,"New version: %d / %d. Loading new default settings",vers,CONFIG_VERSION);      
      if(saveConfig()) Debug.print(DBG_INFO,"Config saved");  //First time use. Save new default values to NVS
    }

  } else {
    Debug.print(DBG_ERROR,"NVS Error");
    nvs.end();
    Debug.print(DBG_INFO,"New version: %d. First saving of settings",CONFIG_VERSION);      
      if(saveConfig()) Debug.print(DBG_INFO,"Config saved");  //First time use. Save new default values to NVS

  }  

  //Define pins directions
  pinMode(FILTRATION_PUMP, OUTPUT);
  pinMode(PH_PUMP, OUTPUT);
  pinMode(CHL_PUMP, OUTPUT);
  pinMode(ROBOT_PUMP,OUTPUT);

  pinMode(RELAY_R0, OUTPUT);
  pinMode(RELAY_R1, OUTPUT);

  pinMode(BUZZER, OUTPUT);

  // As the relays on the board are activated by a LOW level, set all levels HIGH at startup
  digitalWrite(FILTRATION_PUMP,HIGH);
  digitalWrite(PH_PUMP,HIGH); 
  digitalWrite(CHL_PUMP,HIGH);
  digitalWrite(ROBOT_PUMP,HIGH);
  digitalWrite(RELAY_R0,HIGH);
  digitalWrite(RELAY_R1,HIGH);

// Warning: pins used here have no pull-ups, provide external ones
  pinMode(CHL_LEVEL, INPUT);
  pinMode(PH_LEVEL, INPUT);

  // Initialize watch-dog
  esp_task_wdt_init(WDT_TIMEOUT, true);

  //Initialize MQTT
  mqttInit();

  // Initialize WiFi events management (on connect/disconnect)
  WiFi.onEvent(WiFiEvent);
  initTimers();
  connectToWiFi();

  delay(500);    // let task start-up and wait for connection
  while(WiFi.status() != WL_CONNECTED) {
    delay(500);
    Serial.print(".");
  }

  // Config NTP, get time and set system time. This is done here in setup then every day at midnight
  // note: in timeinfo struct, months are from 0 to 11 and years are from 1900. Thus the corrections
  // to pass arguments to setTime which needs months from 1 to 12 and years from 2000...
  // DST (Daylight Saving Time) is managed automatically
  StartTime();
  readLocalTime();
  setTime(timeinfo.tm_hour,timeinfo.tm_min,timeinfo.tm_sec,timeinfo.tm_mday,timeinfo.tm_mon+1,timeinfo.tm_year-100);
  Debug.print(DBG_INFO,"%d/%02d/%02d %02d:%02d:%02d",year(),month(),day(),hour(),minute(),second());

  // Initialize the mDNS library.
  while (!MDNS.begin("PoolMaster")) {
    Debug.print(DBG_ERROR,"Error setting up MDNS responder!");
    delay(1000);
  }
  MDNS.addService("http", "tcp", SERVER_PORT);

  // Start I2C for ADS1115 and status lights through PCF8574A
  Wire.begin(I2C_SDA,I2C_SCL);

  // Init pH, ORP and PSI analog measurements
  AnalogInit();

  // Init Water and Air temperatures measurements
  TempInit();

  // Clear status LEDs

  Wire.beginTransmission(PCF8574ADDRESS);
  Wire.write((uint8_t)0xFF);
  Wire.endTransmission();

  // Initialize PIDs
  storage.PhPIDwindowStartTime  = millis();
  storage.OrpPIDwindowStartTime = millis();

  // Limit the PIDs output range in order to limit max. pumps runtime (safety first...)

  PhPID.SetTunings(storage.Ph_Kp, storage.Ph_Ki, storage.Ph_Kd);
  PhPID.SetControllerDirection(PhPID_DIRECTION);
  PhPID.SetSampleTime((int)storage.PhPIDWindowSize);
  PhPID.SetOutputLimits(0, storage.PhPIDWindowSize);    //Whatever happens, don't allow continuous injection of Acid for more than a PID Window

  OrpPID.SetTunings(storage.Orp_Kp, storage.Orp_Ki, storage.Orp_Kd);
  OrpPID.SetControllerDirection(OrpPID_DIRECTION);
  OrpPID.SetSampleTime((int)storage.OrpPIDWindowSize);
  OrpPID.SetOutputLimits(0, storage.OrpPIDWindowSize);  //Whatever happens, don't allow continuous injection of Chl for more than a PID Window

 // PIDs off at start
  SetPhPID (false);
  SetOrpPID(false);

  //Initialize pump instances with stored config data
  FiltrationPump.SetMaxUpTime(0);     //no runtime limit for the filtration pump

  RobotPump.SetMaxUpTime(0);          //no runtime limit for the robot pump

  PhPump.SetFlowRate(storage.pHPumpFR);
  PhPump.SetTankVolume(storage.pHTankVol);
  PhPump.SetTankFill(storage.AcidFill);
  PhPump.SetMaxUpTime(storage.PhPumpUpTimeLimit * 1000);

  ChlPump.SetFlowRate(storage.ChlPumpFR);
  ChlPump.SetTankVolume(storage.ChlTankVol);
  ChlPump.SetTankFill(storage.ChlFill);
  ChlPump.SetMaxUpTime(storage.ChlPumpUpTimeLimit * 1000);

  // Start filtration pump at power-on if within scheduled time slots -- You can choose not to do this and start pump manually
  if (storage.AutoMode && (hour() >= storage.FiltrationStart) && (hour() < storage.FiltrationStop))
    FiltrationPump.Start();
  else FiltrationPump.Stop();

  // Robot pump off at start
  RobotPump.Stop();

  // Create queue for external commands
  queueIn = xQueueCreate((UBaseType_t)QUEUE_ITEMS_NBR,(UBaseType_t)QUEUE_ITEM_SIZE);

  // Create loop tasks in the scheduler.
  //------------------------------------
  int app_cpu = xPortGetCoreID();

  Debug.print(DBG_DEBUG,"Creating loop Tasks");

  // Create I2C sharing mutex
  mutex = xSemaphoreCreateMutex();

  // Analog measurement polling task
  xTaskCreatePinnedToCore(
    AnalogPoll,
    "AnalogPoll",
    3072,
    NULL,
    1,
    nullptr,
    app_cpu
  );

  // MQTT commands processing
  xTaskCreatePinnedToCore(
    ProcessCommand,
    "ProcessCommand",
    3584,
    NULL,
    1,
    nullptr,
    app_cpu
  );

  // PoolMaster: Supervisory task
  xTaskCreatePinnedToCore(
    PoolMaster,
    "PoolMaster",
    5120,
    NULL,
    1,
    nullptr,
    app_cpu
  );

  // Temperatures measurement
  xTaskCreatePinnedToCore(
    getTemp,
    "GetTemp",
    3072,
    NULL,
    1,
    nullptr,
    app_cpu
  );
  
 // ORP regulation loop
    xTaskCreatePinnedToCore(
    OrpRegulation,
    "ORPRegulation",
    2048,
    NULL,
    1,
    nullptr,
    app_cpu
  );

  // pH regulation loop
    xTaskCreatePinnedToCore(
    pHRegulation,
    "pHRegulation",
    2048,
    NULL,
    1,
    nullptr,
    app_cpu
  );

  // Status lights display
  xTaskCreatePinnedToCore(
    StatusLights,
    "StatusLights",
    2048,
    NULL,
    1,
    nullptr,
    app_cpu
  );  

  // Measures MQTT publish 
  xTaskCreatePinnedToCore(
    MeasuresPublish,
    "MeasuresPublish",
    3072,
    NULL,
    1,
    &pubMeasTaskHandle,               // needed to notify task later
    app_cpu
  );

  // MQTT Settings publish 
  xTaskCreatePinnedToCore(
    SettingsPublish,
    "SettingsPublish",
    3584,
    NULL,
    1,
    &pubSetTaskHandle,                // needed to notify task later
    app_cpu
  );

  // Initialize OTA (On The Air update)
  //-----------------------------------
  ArduinoOTA.setPort(OTA_PORT);
  ArduinoOTA.setHostname("PoolMaster");
  ArduinoOTA.setPasswordHash(OTA_PWDHASH);
  
  ArduinoOTA.onStart([]() {
    String type;
    if (ArduinoOTA.getCommand() == U_FLASH)
      type = "sketch";
    else // U_SPIFFS
      type = "filesystem";
    Debug.print(DBG_INFO,"Start updating %s",type);
  });
  ArduinoOTA.onEnd([]() {
  Debug.print(DBG_INFO,"End");
  });
  ArduinoOTA.onProgress([](unsigned int progress, unsigned int total) {
    esp_task_wdt_reset();           // reset Watchdog as upload may last some time...
    Serial.printf("Progress: %u%%\r", (progress / (total / 100)));
  });
  ArduinoOTA.onError([](ota_error_t error) {
    Debug.print(DBG_ERROR,"Error[%u]: ", error);
    if      (error == OTA_AUTH_ERROR)    Debug.print(DBG_ERROR,"Auth Failed");
    else if (error == OTA_BEGIN_ERROR)   Debug.print(DBG_ERROR,"Begin Failed");
    else if (error == OTA_CONNECT_ERROR) Debug.print(DBG_ERROR,"Connect Failed");
    else if (error == OTA_RECEIVE_ERROR) Debug.print(DBG_ERROR,"Receive Failed");
    else if (error == OTA_END_ERROR)     Debug.print(DBG_ERROR,"End Failed");
  });

  ArduinoOTA.begin();

  //display remaining RAM/Heap space.
  Debug.print(DBG_DEBUG,"[memCheck] Stack: %d bytes - Heap: %d bytes",stack_hwm(),freeRam());

  // Start loops tasks
  Debug.print(DBG_INFO,"Init done, starting loop tasks");
  startTasks = true;

  delay(1000);          // wait for tasks to start

}

bool loadConfig()
{
  nvs.begin("PoolMaster",true);

  storage.ConfigVersion         = nvs.getUChar("ConfigVersion",0);
  storage.Ph_RegulationOnOff    = nvs.getBool("Ph_RegOnOff",false);
  storage.Orp_RegulationOnOff   = nvs.getBool("Orp_RegOnOff",false);  
  storage.AutoMode              = nvs.getBool("AutoMode",true);
  storage.WinterMode            = nvs.getBool("WinterMode",false);
  storage.FiltrationDuration    = nvs.getUChar("FiltrDuration",12);
  storage.FiltrationStart       = nvs.getUChar("FiltrStart",8);
  storage.FiltrationStop        = nvs.getUChar("FiltrStop",20);
  storage.FiltrationStartMin    = nvs.getUChar("FiltrStartMin",8);
  storage.FiltrationStopMax     = nvs.getUChar("FiltrStopMax",22);
  storage.DelayPIDs             = nvs.getUChar("DelayPIDs",0);
  storage.PhPumpUpTimeLimit     = nvs.getULong("PhPumpUTL",900);
  storage.ChlPumpUpTimeLimit    = nvs.getULong("ChlPumpUTL",2500);
  storage.PublishPeriod         = nvs.getULong("PublishPeriod",30000);
  storage.PhPIDWindowSize       = nvs.getULong("PhPIDWSize",60000);
  storage.OrpPIDWindowSize      = nvs.getULong("OrpPIDWSize",60000);
  storage.PhPIDwindowStartTime  = nvs.getULong("PhPIDwStart",0);
  storage.OrpPIDwindowStartTime = nvs.getULong("OrpPIDwStart",0);
  storage.Ph_SetPoint           = nvs.getDouble("Ph_SetPoint",7.3);
  storage.Orp_SetPoint          = nvs.getDouble("Orp_SetPoint",750);
  storage.PSI_HighThreshold     = nvs.getDouble("PSI_High",0.5);
  storage.PSI_MedThreshold      = nvs.getDouble("PSI_Med",0.25);
  storage.WaterTempLowThreshold = nvs.getDouble("WaterTempLow",10.);
  storage.WaterTemp_SetPoint    = nvs.getDouble("WaterTempSet",27.);
  storage.TempExternal          = nvs.getDouble("TempExternal",3.);
  storage.pHCalibCoeffs0        = nvs.getDouble("pHCalibCoeffs0",4.3);
  storage.pHCalibCoeffs1        = nvs.getDouble("pHCalibCoeffs1",-2.63);
  storage.OrpCalibCoeffs0       = nvs.getDouble("OrpCalibCoeffs0",-1189.);
  storage.OrpCalibCoeffs1       = nvs.getDouble("OrpCalibCoeffs1",2564.);
  storage.PSICalibCoeffs0       = nvs.getDouble("PSICalibCoeffs0",1.11);
  storage.PSICalibCoeffs1       = nvs.getDouble("PSICalibCoeffs1",0.);
  storage.Ph_Kp                 = nvs.getDouble("Ph_Kp",2000000.);
  storage.Ph_Ki                 = nvs.getDouble("Ph_Ki",0.);
  storage.Ph_Kd                 = nvs.getDouble("Ph_Kd",0.);
  storage.Orp_Kp                = nvs.getDouble("Orp_Kp",2500.);
  storage.Orp_Ki                = nvs.getDouble("Orp_Ki",0.);
  storage.Orp_Kd                = nvs.getDouble("Orp_Kd",0.);
  storage.PhPIDOutput           = nvs.getDouble("PhPIDOutput",0.);
  storage.OrpPIDOutput          = nvs.getDouble("OrpPIDOutput",0.);
  storage.TempValue             = nvs.getDouble("TempValue",18.);
  storage.PhValue               = nvs.getDouble("PhValue",0.);
  storage.OrpValue              = nvs.getDouble("OrpValue",0.);
  storage.PSIValue              = nvs.getDouble("PSIValue",0.4);
  storage.AcidFill              = nvs.getDouble("AcidFill",100.);
  storage.ChlFill               = nvs.getDouble("ChlFill",100.);
  storage.pHTankVol             = nvs.getDouble("pHTankVol",20.);
  storage.ChlTankVol            = nvs.getDouble("ChlTankVol",20.);
  storage.pHPumpFR              = nvs.getDouble("pHPumpFR",1.5);
  storage.ChlPumpFR             = nvs.getDouble("ChlPumpFR",1.5);

  nvs.end();

  Debug.print(DBG_INFO,"%d",storage.ConfigVersion);
  Debug.print(DBG_INFO,"%d, %d, %d, %d",storage.Ph_RegulationOnOff,storage.Orp_RegulationOnOff,storage.AutoMode,storage.WinterMode);
  Debug.print(DBG_INFO,"%d, %d, %d, %d, %d, %d",storage.FiltrationDuration,storage.FiltrationStart,storage.FiltrationStop,
              storage.FiltrationStartMin,storage.FiltrationStopMax,storage.DelayPIDs);
  Debug.print(DBG_INFO,"%d, %d, %d",storage.PhPumpUpTimeLimit,storage.ChlPumpUpTimeLimit,storage.PublishPeriod);
  Debug.print(DBG_INFO,"%d, %d, %d, %d",storage.PhPIDWindowSize,storage.OrpPIDWindowSize,storage.PhPIDwindowStartTime,storage.OrpPIDwindowStartTime);
  Debug.print(DBG_INFO,"%3.1f, %4.0f, %3.1f, %3.1f, %3.0f, %3.0f, %4.1f, %8.6f, %9.6f, %11.6f, %11.6f, %3.1f, %3.1f",
              storage.Ph_SetPoint,storage.Orp_SetPoint,storage.PSI_HighThreshold,
              storage.PSI_MedThreshold,storage.WaterTempLowThreshold,storage.WaterTemp_SetPoint,storage.TempExternal,
              storage.pHCalibCoeffs0,storage.pHCalibCoeffs1,storage.OrpCalibCoeffs0,storage.OrpCalibCoeffs1,
              storage.PSICalibCoeffs0,storage.PSICalibCoeffs1);
  Debug.print(DBG_INFO,"%8.0f, %3.0f, %3.0f, %6.0f, %3.0f, %3.0f, %7.0f, %7.0f, %4.2f, %4.2f, %4.0f, %4.2f",
              storage.Ph_Kp,storage.Ph_Ki,storage.Ph_Kd,storage.Orp_Kp,storage.Orp_Ki,storage.Orp_Kd,
              storage.PhPIDOutput,storage.OrpPIDOutput,storage.TempValue,storage.PhValue,storage.OrpValue,storage.PSIValue);
  Debug.print(DBG_INFO,"%3.0f, %3.0f, %3.0f, %3.0f, %3.1f, %3.1f ",storage.AcidFill,storage.ChlFill,storage.pHTankVol,storage.ChlTankVol,
              storage.pHPumpFR,storage.ChlPumpFR);

  return (storage.ConfigVersion == CONFIG_VERSION);
}

bool saveConfig()
{
  nvs.begin("PoolMaster",false);

  size_t i = nvs.putUChar("ConfigVersion",storage.ConfigVersion);
  i += nvs.putBool("Ph_RegOnOff",storage.Ph_RegulationOnOff);
  i += nvs.putBool("Orp_RegOnOff",storage.Orp_RegulationOnOff);  
  i += nvs.putBool("AutoMode",storage.AutoMode);
  i += nvs.putBool("WinterMode",storage.WinterMode);
  i += nvs.putUChar("FiltrDuration",storage.FiltrationDuration);
  i += nvs.putUChar("FiltrStart",storage.FiltrationStart);
  i += nvs.putUChar("FiltrStop",storage.FiltrationStop);
  i += nvs.putUChar("FiltrStartMin",storage.FiltrationStartMin);
  i += nvs.putUChar("FiltrStopMax",storage.FiltrationStopMax);
  i += nvs.putUChar("DelayPIDs",storage.DelayPIDs);
  i += nvs.putULong("PhPumpUTL",storage.PhPumpUpTimeLimit);
  i += nvs.putULong("ChlPumpUTL",storage.ChlPumpUpTimeLimit);
  i += nvs.putULong("PublishPeriod",storage.PublishPeriod);
  i += nvs.putULong("PhPIDWSize",storage.PhPIDWindowSize);
  i += nvs.putULong("OrpPIDWSize",storage.OrpPIDWindowSize);
  i += nvs.putULong("PhPIDwStart",storage.PhPIDwindowStartTime);
  i += nvs.putULong("OrpPIDwStart",storage.OrpPIDwindowStartTime);
  i += nvs.putDouble("Ph_SetPoint",storage.Ph_SetPoint);
  i += nvs.putDouble("Orp_SetPoint",storage.Orp_SetPoint);
  i += nvs.putDouble("PSI_High",storage.PSI_HighThreshold);
  i += nvs.putDouble("PSI_Med",storage.PSI_MedThreshold);
  i += nvs.putDouble("WaterTempLow",storage.WaterTempLowThreshold);
  i += nvs.putDouble("WaterTempSet",storage.WaterTemp_SetPoint);
  i += nvs.putDouble("TempExternal",storage.TempExternal);
  i += nvs.putDouble("pHCalibCoeffs0",storage.pHCalibCoeffs0);
  i += nvs.putDouble("pHCalibCoeffs1",storage.pHCalibCoeffs1);
  i += nvs.putDouble("OrpCalibCoeffs0",storage.OrpCalibCoeffs0);
  i += nvs.putDouble("OrpCalibCoeffs1",storage.OrpCalibCoeffs1);
  i += nvs.putDouble("PSICalibCoeffs0",storage.PSICalibCoeffs0);
  i += nvs.putDouble("PSICalibCoeffs1",storage.PSICalibCoeffs1);
  i += nvs.putDouble("Ph_Kp",storage.Ph_Kp);
  i += nvs.putDouble("Ph_Ki",storage.Ph_Ki);
  i += nvs.putDouble("Ph_Kd",storage.Ph_Kd);
  i += nvs.putDouble("Orp_Kp",storage.Orp_Kp);
  i += nvs.putDouble("Orp_Ki",storage.Orp_Ki);
  i += nvs.putDouble("Orp_Kd",storage.Orp_Kd);
  i += nvs.putDouble("PhPIDOutput",storage.PhPIDOutput);
  i += nvs.putDouble("OrpPIDOutput",storage.OrpPIDOutput);
  i += nvs.putDouble("TempValue",storage.TempValue);
  i += nvs.putDouble("PhValue",storage.PhValue);
  i += nvs.putDouble("OrpValue",storage.OrpValue);
  i += nvs.putDouble("PSIValue",storage.PSIValue);
  i += nvs.putDouble("AcidFill",storage.AcidFill);
  i += nvs.putDouble("ChlFill",storage.ChlFill);
  i += nvs.putDouble("pHTankVol",storage.pHTankVol);
  i += nvs.putDouble("ChlTankVol",storage.ChlTankVol);
  i += nvs.putDouble("pHPumpFR",storage.pHPumpFR);
  i += nvs.putDouble("ChlPumpFR",storage.ChlPumpFR);

  nvs.end();

  Debug.print(DBG_INFO,"Bytes saved: %d / %d\n",i,sizeof(storage));
  return (i == sizeof(storage)) ;

}

// functions to save any type of parameter (4 overloads with same name but different arguments)

bool saveParam(const char* key, uint8_t val)
{
  nvs.begin("PoolMaster",false);
  size_t i = nvs.putUChar(key,val);
  return(i == sizeof(val));
}

bool saveParam(const char* key, bool val)
{
  nvs.begin("PoolMaster",false);
  size_t i = nvs.putBool(key,val);
  return(i == sizeof(val));
}

bool saveParam(const char* key, unsigned long val)
{
  nvs.begin("PoolMaster",false);
  size_t i = nvs.putULong(key,val);
  return(i == sizeof(val));
}

bool saveParam(const char* key, double val)
{
  nvs.begin("PoolMaster",false);
  size_t i = nvs.putDouble(key,val);
  return(i == sizeof(val));
}
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
void loop()
{
  delay(1000);
  vTaskDelete(nullptr);
}

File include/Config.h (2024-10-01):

// Firmware revisions
#define FIRMW "ESP-3.3b"
#define TFT_FIRMW "TFT-2.0"						   

#define DEBUG_LEVEL DBG_INFO     // Possible levels : NONE/ERROR/WARNING/INFO/DEBUG/VERBOSE

//Version of config stored in EEPROM
//Random value. Change this value (to any other value) to revert the config to default values
#define CONFIG_VERSION 50

// WiFi credentials
#define WIFI_NETWORK "YOUR_WIFI_NETWORK_ID"
#define WIFI_PASSWORD "YOUR_WIFI_NETWORK_PWD"
#define OTA_PWDHASH   "Your_OTA_password_hash"
#ifdef DEVT
  #define HOSTNAME "PoolMaster_Dev"
#else
  #define HOSTNAME "PoolMaster"
#endif 

// Mail parameters and credentials
#define EMAIL_ALERT    // Comment this line to disable Email alerting
#define SMTP_HOST "your smtp server"
#define SMTP_PORT 587  // check the port number
#define AUTHOR_EMAIL "your email address"
#define AUTHOR_LOGIN "your user name"
#define AUTHOR_PASSWORD "your password"
#define RECIPIENT_EMAIL "your recipient email address"

// PID Directions (either DIRECT or REVERSE depending on Ph/Orp correction vs water properties)
#define PhPID_DIRECTION REVERSE
#define OrpPID_DIRECTION DIRECT

#define FILTRATION_PUMP 32
#define ROBOT_PUMP	    33
#define PH_PUMP         25
#define CHL_PUMP        26
#define RELAY_R0        27   // Projecteur
#define RELAY_R1         4   // Spare, not connected

//Digital input pins connected to Acid and Chl tank level reed switches
#define CHL_LEVEL       39   // not wired. Use NO_LEVEL option of Pump class
#define PH_LEVEL        36   //                - " -

//One wire bus for the air/water temperature measurement
#define ONE_WIRE_BUS_A  18
#define ONE_WIRE_BUS_W  19

//I2C bus for analog measurement with ADS1115 of pH, ORP and water pressure 
//and status LED through PCF8574A 
#define I2C_SDA			21
#define I2C_SCL			22
#define PCF8574ADDRESS  0x38 // 0x20 for PCF8574(N) or 0x38 for PCF8574A(N)


//Type of pH and Orp sensors acquisition :
//INT_ADS1115 : single ended signal with internal ADS1115 ADC (default)
//EXT_ADS1115 : differential signal with external ADS1115 ADC (Loulou74 board)
#define EXT_ADS1115
#define INT_ADS1115_ADDR ADS1115ADDRESS
#define EXT_ADS1115_ADDR ADS1115ADDRESS+1 // or +2 or +3 depending on board setup

// Buzzer
#define BUZZER           2

#define WDT_TIMEOUT     10

// Server port
#define SERVER_PORT 8060

//OTA port
#define OTA_PORT    8063

//12bits (0,06°C) temperature sensors resolution
#define TEMPERATURE_RESOLUTION 12

//MQTT stuff including local broker/server IP address, login and pwd
//------------------------------------------------------------------

//interval (in millisec) between MQTT publishement of measurement data
#define PUBLISHINTERVAL 30000

#define MQTT_SERVER_IP IPAddress(000, 000, 000, 000)
#define MQTT_SERVER_PORT 1883

// Uncomment if MQTT broker needs login/pwd
//#define MQTT_LOGIN 				
//#define MQTT_SERVER_ID    "ESP32Pool"		   // MQTT server ID
//#define MQTT_SERVER_LOGIN "Your_Login"
//#define MQTT_SERVER_PWD   "Your_Pwd" 				

// Topic used in DEVT or OPER mode

#ifdef DEVT
  #define POOLTOPIC "Home/Pool6/"
#else
  #define POOLTOPIC "Home/Pool/"
#endif 

// Robot pump timing
#define ROBOT_DELAY 60     // Robot start delay after filtration in mn
#define ROBOT_DURATION 90  // Robot cleaning duration

//Display timeout before blanking
//-------------------------------
#define TFT_SLEEP 60000L 

// Loop tasks scheduling parameters
//---------------------------------
// T1: AnalogPoll
// T2: PoolServer
// T3: PoolMaster
// T4: getTemp
// T5: OrpRegulation
// T6: pHRegulation
// T7: StatusLights
// T8: PublishMeasures
// T9: PublishSettings 

//Periods 
// Task9 period is initialized with PUBLISHINTERVAL and can be changed dynamically
#define PT1 125
#define PT2 500
#define PT3 500
#define PT4 1000 / (1 << (12 - TEMPERATURE_RESOLUTION))
#define PT5 1000
#define PT6 1000
#define PT7 3000
#define PT8 30000

//Start offsets to spread tasks along time
// Task1 has no delay
#define DT2 190/portTICK_PERIOD_MS
#define DT3 310/portTICK_PERIOD_MS
#define DT4 440/portTICK_PERIOD_MS
#define DT5 560/portTICK_PERIOD_MS
#define DT6 920/portTICK_PERIOD_MS
#define DT7 100/portTICK_PERIOD_MS
#define DT8 570/portTICK_PERIOD_MS
#define DT9 940/portTICK_PERIOD_MS

//#define CHRONO                    // Activate tasks timings traces for profiling
//#define SIMU                      // Used to simulate pH/ORP sensors. Very simple simulation:
                                    // the sensor value is computed from the output of the PID 
                                    // loop to reach linearly the theorical value produced by this
                                    // output after one hour

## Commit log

2021-01-30 Add files via upload
    Lot of cosmetic mods. Use Arduino_DebugUtils library. Improve update of Nextion display when awaken.
2021-02-08 Minor mods
    - streamline debug traces with Arduino_DebugUtils library
    - add air temperature measurement on another 1wire bus
    - modify filtration duration vs water temp
    - add PID running indications on Nextion display
    - review display refresh at wakeup after sleep
2021-02-12 Add Grafana dashboard
    update nodered dashboard:
    - add air temperature gauge
    - add current time
2021-03-01 Version 6 - FreeRTOS functions
    Use FreeRTOS for tasks and queue management. 9 tasks scheduled in preemptive/round-robin manner.
    Implement Winter mode (no PID but still automatic filtration).
2021-03-06 Protect I2C bus by mutex
    Avoid bus conflict between AnaloPoll and StatusLights tasks
    [Loops.cpp, Setup.cpp]
2021-03-12 Fix compiler optimisation in release mode
    Put some variables volatile to avoid compiler optimisation
    [Nextion.cpp, Setup.cpp]
2021-03-17 Add PDF of the board
2021-03-30 Create Gerber 2.zip
    Fabrication files for mother board
2021-04-08 Add IFTTT notifications in case of alarm
    + some minor mods and fixes
    [Loops.cpp, PoolServer.cpp, Setup.cpp]
2022-03-07 Version ESP-2.9A
    - add low water pressure threshold command in poolserver.cpp
    - move custom IDs into config.h (WiFi and IFTTT)
    - some minor mods
2022-10-18 Update Setup.cpp
    Wait for SNTP init completion before reading time. Avoid some erratic time initialization on startup.
    [Setup.cpp]
2023-03-06 MQTT credentials definition
    If MQTT broker needs authentication, add MQTT_LOGIN parameter to take credentials into consideration
    [Config.h]
2023-07-30 Publish clearing of error(s)
    When cleraing error(s), publish cleared error topic
    [PoolServer.cpp]
2023-08-17 ESP-3.0
    Greatly simplify the Nextion update function (twice less code) by using Nextion variables and deporting code to the Nextion pages timers. Commands are sent only when display is ON.
    Some cosmetic changes in config.h file.
2023-12-23 Display blanking inhibit when in calibration pages
    Inhibit display blanking when in calibration pages
2024-02-14 Create CAD_files.zip
    CAD files.
2024-03-14 Create Gerber 3.zip
    Add I2C-5V K14 connector for Ph-Orp Loulou74 board
2024-03-14 Create PoolMaster 2.PDF
    Add I2C-5V connector for Loulou74 ph-Orp board
2024-03-14 Create CAD_files 2.zip
    Add I2C-5V connector K14 for Loulou74 Ph-Orp board
2024-03-16 Compatibility with "Loulou74" pH-Orp board
    This version is associated with the new hardware allowing the connection of the pH-Orp board designed by Loulou74.
    See config.h to configure the setup.
2024-03-19 Create Bill of Materials-PoolMaster.xlsx
    Create BOM
    [Bill of Materials-PoolMaster.xlsx]
2024-03-19 Compatibility with "Loulou74" pH-Orp board
2024-03-22 WiFi reconnect workaround
    With Arduino core 2.0.14, WiFi driver generates spurious deconnected event before connected event, leading to erratic reconnection/deconnection loop. Reconnect is performed only if WiFi is not connected when those events are received.
    [Config.h]
2024-04-05 Manage negative voltages on pH-Orp board
2024-05-23 pH_Orp Board V2
    [BOM.xlsx]
2024-07-06 Replace IFTTT notify by emails
    [Config.h, Setup.cpp]
2024-08-25 Create Pick Place for ph_Orp_Board.csv
    [Pick Place for ph_Orp_Board.csv]
2024-09-27 Minor changes
    - WiFi reconnect procedure change, let system doing the job
    - no more use of Arduino Strings, replaced by char arrays
    - correction of one bug in array dimension in Publish.cpp
    - add config.h define to enable email alerting
    [Config.h, Nextion.cpp, Publish.cpp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]
2025-01-14 Ph Orp Board CAD files
    [pH_Orp_Board.SchDoc, ph_Orp_Board.PcbDoc]
